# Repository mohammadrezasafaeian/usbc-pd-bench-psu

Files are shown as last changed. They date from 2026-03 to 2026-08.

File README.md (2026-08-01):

<div align="center">

# USB-C PD Bench Power Supply

### 0 – 36 V · 0 – 3 A · from a phone charger

4-switch synchronous buck-boost pre-regulator followed by a PNP-Darlington linear post-regulator —
laboratory-grade output from a USB-C source.





**[📄 Read the schematic →](sch.pdf)**

</div>

---

## Specification

| | |
|---|---|
| **Output** | 0 – 36 V, 0 – 3 A, continuously adjustable |
| **Max power** | limited by the source contract, not by the topology — see below |
| **Input** | USB-C — any PD contract, **or a legacy 5 V port**.  The buck-boost stage means the input voltage never limits the output voltage. |
| **Topology** | switching pre-regulator + linear post-regulator |
| **Ripple** | linear final stage — switching noise never reaches the output |
| **Protection** | polyfuse · 24 V TVS · hardware over-current under 1 µs · firmware OVP |
| **Control** | STM32G030C8T6, 5 kHz PI loop |
| **Interface** | 0.96″ OLED · rotary encoder · 3 keys · 10 indicator LEDs |

---

## Architecture

```mermaid
flowchart LR
    USB["USB-C input<br/>5 to 20 V"] --> PD["CH224K<br/>PD trigger"]
    PD --> BB["4-switch buck-boost<br/>250 kHz"]
    BB -->|"V_OUT + 2 V"| LIN["PNP Darlington<br/>linear post-reg"]
    LIN --> SNS["0R05 shunt<br/>INA181A2"]
    SNS --> OUT["OUTPUT<br/>0 to 36 V / 0 to 3 A"]
    MCU["STM32G030C8T6<br/>PWM, ADC, PI loop, PDO select"]
    MCU -.->|"CFG"| PD
    MCU -.->|"gate PWM"| BB
    MCU -.->|"V_REF"| LIN
    SNS -.->|"I sense"| MCU
    UI["OLED, encoder, keys"] -.-> MCU
    style USB fill:#e8f0fe,stroke:#1f6feb,stroke-width:2px
    style OUT fill:#fde8e8,stroke:#c62828,stroke-width:2px
    style BB fill:#e8f5e9,stroke:#2e7d32,stroke-width:2px
    style LIN fill:#e8f5e9,stroke:#2e7d32,stroke-width:2px
    style SNS fill:#e8f5e9,stroke:#2e7d32,stroke-width:2px
    style MCU fill:#fff4e5,stroke:#e07b00,stroke-width:2px
    style UI fill:#f3e5f5,stroke:#7b1fa2,stroke-width:2px
```

**Two stages, because neither alone is enough.** A switcher is efficient but noisy. A linear
regulator is quiet but burns the entire input-to-output difference as heat.

So the switcher does the bulk conversion and parks itself ~2 V above the target; the linear stage
drops only that last 2 V and absorbs all the ripple.

> Feeding the linear stage a fixed 20 V at 1 V / 3 A output would burn **57 W**.
> Tracking headroom keeps it near **6 W**.

Because the pre-regulator both bucks *and* boosts, the output voltage is independent of whatever
the charger negotiated. A 5 V source can drive a 36 V output; it just cannot drive it at 3 A.

---

## Adaptive PD negotiation

**The buck-boost stage decouples input from output.** Any negotiated voltage can produce any
output voltage — 20 V out from a 5 V contract works fine electrically (boost duty 0.77). The
contract does not limit the output *voltage*.

What it limits is **current**, because power has to balance:

| Contract | at 5 V out | at 12 V out | at 24 V out | at 36 V out |
|---|:---:|:---:|:---:|:---:|
| 5 V / 3 A — 15 W | 2.0 A | 0.9 A | 0.5 A | 0.3 A |
| 9 V / 3 A — 27 W | 3.0 A | 1.7 A | 0.9 A | 0.6 A |
| 12 V / 3 A — 36 W | 3.0 A | 2.3 A | 1.2 A | 0.8 A |
| 15 V / 3 A — 45 W | 3.0 A | 2.8 A | 1.5 A | 1.1 A |
| **20 V / 1.75 A — 35 W** | 3.0 A | 2.2 A | 1.2 A | 0.8 A |
| 20 V / 3 A — 60 W | 3.0 A | 3.0 A | 2.1 A | 1.4 A |

So a **35 W charger reaches 36 V out at ~0.8 A**, and 20 V at ~1.2 A. The contract never blocks a
voltage — it only caps the current. 3 A is the hardware ceiling set by the shunt and the pass
device.

### So why negotiate at all?

Two reasons, and neither is about reaching the voltage:

```mermaid
flowchart LR
    S(["V_OUT setpoint"]) --> WHY["pick the contract that<br/>keeps duty in range<br/>and has the power"]
    WHY --> A["0 to 4 V<br/>request 9 V"]
    WHY --> B["4 to 9 V<br/>request 12 V"]
    WHY --> C["9 to 13 V<br/>request 15 V"]
    WHY --> D["13 to 36 V<br/>request 20 V"]
    A --> A2["avoids tiny duty<br/>at low output"]
    B --> B2["duty 0.45 to 0.9"]
    C --> C2["headroom for current"]
    D --> D2["least step-up,<br/>best efficiency"]
    style S fill:#e8f0fe,stroke:#1f6feb,stroke-width:2px
    style WHY fill:#fff4e5,stroke:#e07b00,stroke-width:2px
    style A fill:#e8f5e9,stroke:#2e7d32
    style B fill:#e8f5e9,stroke:#2e7d32
    style C fill:#e8f5e9,stroke:#2e7d32
    style D fill:#e8f5e9,stroke:#2e7d32
```

**Duty-cycle range.** With 20 V in and 3 V out, the gate driver's 520 ns dead-time leaves only
~80 ns of real conduction and the loop pulse-skips. Requesting a lower voltage keeps the duty
cycle controllable.

**Efficiency.** Converting 20 V down to 5 V wastes more than converting 9 V down to 5 V. Picking
the nearest useful contract minimises the conversion ratio.

The firmware reads the source's advertised PDO list and takes the best available — it does not
assume 60 W is on offer. Boundaries carry 1.5 V of hysteresis, and the output is disabled during
renegotiation.

---

## Design highlights

<table>
<tr><td width="50%" valign="top">

### 🔌 Works on any USB-C port

Full PD gets the whole 0–20 V range. A **legacy 5 V port** still boots and runs, clamped to what
it can deliver.

Two details make that work:

- the logic LDO is fed from the **+12 V rail**, not VBUS — a legacy port sits at ~4.75 V, below
  the regulator's dropout
- **CFG1 is pulled high**, so a bare board requests 5 V before firmware even runs

</td><td width="50%" valign="top">

### 🛡 Protection that doesn't need firmware

A comparator pulls both gate drivers down in **under 1 µs**, independent of the MCU.

The fault LED lights **even if the processor has crashed** — which is the entire point of a
hardware trip.

Firmware then latches the fault and holds the output off until it's cleared.

</td></tr>
<tr><td valign="top">

### 🛑 Output kill is never in a menu

A **dedicated OUTPUT key** on its own interrupt.

If the board under test starts smoking, one press stops it — no scrolling, no mode, no waiting
for the UI task to notice.

</td><td valign="top">

### 🔍 24 test points

Kelvin taps at the current shunt, paired grounds so every scope probe has a short return, and
1.0 mm pads on the switch nodes to keep copper on the high-dv/dt net minimal.

</td></tr>
</table>

---

## Control loop

```mermaid
flowchart LR
    SET(["V_SET from UI"]) --> DAC["PWM-DAC<br/>2-pole RC"]
    DAC --> EA["Error amp<br/>LM358"]
    FB["Output divider"] --> EA
    EA --> PASS["PNP Darlington<br/>base drive"]
    PASS --> VOUT(["V_OUT"])
    VOUT --> FB
    VOUT -.->|"ADC"| PI["PI loop<br/>5 kHz"]
    PI -.->|"V_PRE tracks V_OUT"| PRE["Buck-boost duty"]
    ISNS["Shunt + INA181A2"] -.-> PI
    ISNS -.->|"over 3.2 A"| TRIP["Comparator<br/>under 1 us"]
    TRIP -.->|"SHDN_N"| PRE
    style SET fill:#e8f0fe,stroke:#1f6feb
    style VOUT fill:#fde8e8,stroke:#c62828,stroke-width:2px
    style TRIP fill:#fde8e8,stroke:#c62828,stroke-width:2px
    style PI fill:#fff4e5,stroke:#e07b00
```

Headroom is **adaptive**, not a flat 2 V:

```
V_head = clamp(1.6 V + 0.35 Ω × I_out,  2.0 V,  3.0 V)
```

Slew-limited so the pre-regulator leads on rising steps and lags on falling ones — V_PRE must
never dip below V_OUT + V_CE(sat).

---

## User interface

| Control | Function |
|---|---|
| **Rotary encoder** | adjust the selected field |
| **Encoder push** | coarse / fine step (×1 · ×10 · ×100) |
| **OUTPUT** | dedicated on/off — own interrupt, always responsive |
| **SELECT** | cycle V-set → I-limit → digit |
| **BACK** | back; long-press clears a latched fault |

**10 indicator LEDs** — three rail-health, output live, constant-current mode, firmware heartbeat,
PD contract status, fault, and UART activity.

Seven are driven directly by hardware, which is deliberate:

- **PD_PG** is driven by the PD controller itself — it shows at a glance whether you got a real
  contract or fell back to legacy 5 V
- **FAULT** is driven by the over-current comparator, so it lights *even when the MCU is dead*.
  A firmware-driven fault lamp cannot do that.

The remaining three — **OUT**, **CC** and **HB** — are on GPIO, and the firmware uses them as a
diagnostic code so a fault can be identified without a scope or a serial cable.

### Planned blink codes

> Firmware is not yet written. This is the diagnostic scheme the hardware supports.

`HB` carries the rhythm; `OUT` and `CC` encode the fault as two bits.

| HB | OUT | CC | Meaning |
|:---|:---:|:---:|:---|
| steady 1 Hz | — | — | running normally |
| 2 blinks | off | off | over-current trip |
| 2 blinks | **on** | off | over-voltage |
| 2 blinks | off | **on** | over-temperature |
| 2 blinks | **on** | **on** | pre-regulator lost tracking |
| 3 blinks | off | off | PD negotiation failed |
| 3 blinks | **on** | off | legacy 5 V port — output range clamped |
| 3 blinks | off | **on** | ADC or reference out of range |
| solid on | **on** | **on** | firmware fault — watchdog reset pending |

Three GPIO-driven LEDs give **8 distinguishable fault states**, and the two hardware-driven lamps
(PD_PG, FAULT) stay valid even if the processor has stopped — so a dead MCU is itself
diagnosable.

---

## Engineering decisions worth asking about

> These are the judgement calls. Reasoning is in [`AUTHORSHIP.md`](AUTHORSHIP.md) and in notes on
> the sheets themselves.

- **The ground plane is not split** between the switching and linear sections. The stages are in
  *series*, so there is one return current — a slot would force it to detour and enlarge the loop.
  Separation is done by placement, with the analog reference starred at the output cap negative.
- **The current shunt is high-side**, so the output negative stays at true ground and the sense
  network carries only microamps.
- **The pass device is a PNP Darlington**, not an NPN follower — an NPN would need V_OUT + 1 V of
  drive, impossible at the top of the range.
- **Linear headroom is adaptive** and slew-limited, not a fixed offset.

---

## Firmware

Bare-metal C, no HAL. **3.0 KB flash, 40 bytes RAM.**

```bash
cd firmware && make
```

The analogue loop does the fast regulation; firmware supervises:

| Layer | Does | Speed |
|---|---|---|
| LM358 + PNP Darlington | holds V_OUT at the reference | analogue |
| Comparator → SHDN_N | kills the drivers on over-current | < 1 µs, no MCU |
| Firmware PI loop | keeps V_PRE ≈ V_OUT + headroom | 5 kHz |
| Supervisor | limits, PDO choice, UI, diagnostics | 100 Hz |

### Battery emulation

A cell sags under load, and that is the entire model:

```c
V_out = V_oc − I_load × R_internal
```

Both adjustable from the panel — 3.7 V / 100 mΩ for a Li-ion cell, 12.6 V /
20 mΩ for a small lead-acid pack. The current sense and voltage reference are
already in the loop, so this needs no extra hardware.

**Source-side only.** A real battery accepts charge; sinking current needs a
two-quadrant output stage, which the PNP pass device cannot do. That is the
next hardware revision.

See [`firmware/README.md`](firmware/README.md) for the pin map and the
diagnostic blink codes.

---

## Verification

| Check | Result |
|---|---|
| KiCad ERC errors | **0** |
| Orphan / unconnected parts | **0** |
| Dangling or single-pin nets | **0** |
| Shorted two-terminal parts | **0** |
| Auto-named nets | **0** — all **85** nets named for layout |
| Items off-page or clashing with the title block | **0** |
| Analogue nets on real ADC channels | **6 / 6** |
| Firmware pin map vs schematic netlist | **27 / 27 match** |
| Firmware build | **clean, 0 warnings** |

Several faults were caught during checking that had passed visual inspection — a pass transistor
whose collector and emitter had landed on the same net, six UI inputs chained together through
their debounce grounds, and reversed LED polarity. Details in [`AUTHORSHIP.md`](AUTHORSHIP.md).

---

## Revision history

| Rev | Status | What changed |
|---|---|---|

| **early** | superseded | single-sheet layout — included as page 4 of the PDF |
| **v1.1** | superseded | snubbers · +12 V gate rail on-sheet · hardware OCP · IRS2104 drivers · INA181A2 sense · STM32G030C8T6 · full UI. Output 0–20 V. |
| **v1.2** | **current** | output range raised to **0–36 V** (63 V bulk caps, rescaled dividers); all analogue nets moved onto real ADC channels; firmware added |

The earlier single-sheet revision had no snubbers on the switch nodes and left the +12 V gate
rail as an off-sheet module. Both are resolved here.

---

## Repository

| File | |
|---|---|
| **[`sch.pdf`](sch.pdf)** | **4-page schematic — start here** |
| **[`docs/design-evolution.pdf`](docs/design-evolution.pdf)** | **how the design got here — every revision, v0.3 to v1.3** |
| `usbc_pd_psu.kicad_sch` | KiCad 9 project (root sheet) |
| `power.kicad_sch` | sheet 1 — input, PD trigger, 12 V rail, buck-boost, drivers, OCP |
| `control.kicad_sch` | sheet 2 — post-regulator, current sense, MCU, UI |
| `bom.csv` · `netlist.net` · `erc.rpt` | outputs |
| `firmware/` | bare-metal C: control loop, battery emulation, diagnostics (`hw` / `control` / `pd` / `ui`) |
| [`AUTHORSHIP.md`](AUTHORSHIP.md) | design reasoning and provenance |

Drawn in **KiCad 9** using stock symbol and footprint libraries only — no custom parts, so the
project opens cleanly on any KiCad 9 installation.

---

## Status and honest caveats

> **Design complete, not yet built.** No hardware has been assembled or tested.

Known open items, carried deliberately:

- Dead-time is **13 % of the switching period** at 250 kHz. Dropping to 150 kHz with a 47 µH
  inductor would cut it to 7.8 %, at the cost of a physically larger inductor.
- V_PRE reaches 39 V at full output. The 60 V bridge FETs keep 54 % margin; output and V_PRE
  bulk caps are 63 V parts. Going beyond 36 V would need 100 V FETs.
- Input capacitance exceeds the USB hot-plug limit. PD sources tolerate it in practice; strict
  compliance needs a soft-start FET.

---

<div align="center">

**Mohammadreza Safaeian**

[m.re.safaeian@gmail.com](mailto:m.re.safaeian@gmail.com) · [github.com/mohammadrezasafaeian](https://github.com/mohammadrezasafaeian)

© 2026 Mohammadreza Safaeian. All rights reserved — see [LICENSE](LICENSE).

</div>

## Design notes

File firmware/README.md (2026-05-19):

# Firmware

Bare-metal C for the STM32G030C8T6. No HAL, no RTOS.

```
firmware/
  main.c          init and the 5 kHz / 100 Hz loop
  hw.c            GPIO, ADC, PWM  — the only file that touches registers
  control.c       PI loop, current limit, battery emulation
  pd.c            PDO selection and renegotiation
  ui.c            encoder, buttons, LED codes
  psu.h           shared state and cross-module declarations
  board.h         pin map, divider ratios, limits
  stm32g030.h     register map
  startup.c       vector table, .data / .bss setup
  stm32g030.ld    64 KB flash, 8 KB RAM
  Makefile
```

`board.h` is the only file that changes if the wiring changes.

## Build

```bash
cd firmware
make            # -> main.elf, main.bin
make flash      # OpenOCD over SWD
```

Needs `gcc-arm-none-eabi`. **3.0 KB flash (4.7 %)**, **40 bytes RAM (0.5 %)**.

---

## How the regulation is split

| Layer | Does | Speed |
|---|---|---|
| LM358 + PNP Darlington | holds V_OUT at the reference | analogue |
| Comparator + SHDN_N | kills the drivers on over-current | < 1 µs, no MCU |
| Firmware PI loop | keeps V_PRE ≈ V_OUT + headroom | 5 kHz |
| Firmware supervisor | limits, PDO choice, UI, diagnostics | 100 Hz |

Firmware never regulates the output directly. It sets the reference through a
PWM DAC and keeps the pre-regulator a sensible distance above the output:

```c
V_head = clamp(2.0 V + 0.35 Ω × I_out, 2.0 V, 3.0 V)
```

A flat 2 V is thin at 3 A once Darlington saturation, the shunt drop and the
switcher's droop are added up.

`SHDN_N` is open drain and wired-AND with the comparator, so firmware can only
*assert* shutdown — never override the hardware trip.

---

## Modes

**Supply** — constant voltage with a current limit. At the limit the firmware
walks the reference down and lights CC; the analogue loop does the limiting.

**Battery** — a cell sags under load, and that is the whole model:

```c
V_out = V_oc − I_load × R_internal
```

Both adjustable from the panel — 3.7 V / 100 mΩ for a Li-ion cell, 12.6 V /
20 mΩ for a small lead-acid pack.

Source side only: a real battery accepts charge, and the PNP cannot sink. That
needs a two-quadrant output stage — the next hardware revision.

---

## PDO selection

The buck-boost decouples input from output, so **any contract reaches any
output voltage**. What a contract limits is *current*.

| Setpoint | Requests | Why |
|---|---|---|
| 0 – 4 V | 9 V | keeps duty off the dead-time floor |
| 4 – 9 V | 12 V | |
| 9 – 13 V | 15 V | |
| 13 – 36 V | 20 V | least step-up ratio |

On a legacy 5 V-only port the range clamps to 4 V and `FAULT_LEGACY_CLAMP`
lights — the supply still works, with a smaller envelope. The output is
dropped across a renegotiation, because VBUS collapses briefly.

---

## Diagnostic codes

Three LEDs are on GPIO; the other seven are wired to hardware signals, so the
fault lamp still works when the MCU is dead.

| HB | OUT | CC | Meaning |
|---|---|---|---|
| 1 Hz heartbeat | output live | in CC | normal |
| 2 blinks | · | · | over-current |
| 2 blinks | on | · | over-voltage |
| 2 blinks | · | on | over-temperature |
| 2 blinks | on | on | tracking — pre-reg lost the output |
| 3 blinks | · | · | PD negotiation failed |
| 3 blinks | on | · | legacy 5 V port, range clamped |
| solid | on | on | firmware fault |

Press **OUTPUT** to clear a fault and toggle the output, or hold **BACK** for
about a second to clear it without touching the output.

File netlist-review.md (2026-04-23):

# Netlist review

Checks run against the exported netlist rather than the drawing, because
most of these are invisible on a sheet that looks correct.

| Check | Result |
|---|---|
| every part has a footprint | pass |
| no two-terminal part shorted end to end | pass |
| no net with a single node | pass |
| no two labels differing only by case or a character | pass |
| every symbol inside a sheet frame | pass |
| every MCU pin either assigned or explicitly no-connect | pass |
| analogue nets land on pins that have an ADC channel | **fail** |
| feedback divider reaches the error amplifier | **fail** |

## Analogue nets on pins with no ADC

`ADC_VBUS`, `ADC_VPRE`, `ADC_VOUT` and `ISNS_OUT` sit on PD2, PD3, PC6 and
PC7.  None of those has an ADC channel on this part, so not one of the four
measurements can be taken.  They need to move to PA0, PA1, PA4 and PA5.

## Feedback divider does not reach the error amplifier

`VOUT_FB` reaches only an MCU analogue input.  The error amplifier's
inverting input is on a separate net that sees only its compensation
capacitor, so the loop has no DC path around it.  Both need to be one node.

The first is fixed in the next revision.  The second is deeper than a pin
move and is carried forward.

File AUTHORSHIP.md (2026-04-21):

# Authorship and provenance

**Author:** Mohammadreza Safaeian
**Contact:** m.re.safaeian@gmail.com · mohammad.rsafaeian@gmail.com
**Repository:** https://github.com/mohammadrezasafaeian
**Copyright:** © 2026 Mohammadreza Safaeian. All rights reserved.

This is an original design. It is not derived from a reference design, an
application-note schematic, or any downloaded project.

---

## What makes that checkable

Anyone can type a name into a title block. These are the things that are
actually hard to fake, in descending order of usefulness:

### 1. The design evolved through revisions, and the earlier one is included

`docs/earlier-revision.png` is my previous KiCad revision (the earlier revision:
CH32V003 MCU, IR2104 drivers, discrete LM358 current sense). It is bound into
`sch.pdf` as page 4.

Rev C is the redraw that fixes the problems in it:

| the earlier revision (previous) | Rev C (this design) |
|---|---|
| no snubbers on the switch nodes | RC snubbers (4R7 + 2n2) on both |
| +12 V gate rail left as an off-sheet module — **unbuildable** | MT3608 boost on-sheet |
| IR2104 drivers (V_IH out of spec at 3.3 V) | IRS2104 (V_IH 2.5 V) |
| discrete LM358 current sense | INA181A2 + 0R05 shunt |
| CH32V003 — out of I/O once the UI was added | STM32G030C8T6, ~18 pins spare |
| no hardware over-current path | LM2903 trip, < 1 µs, firmware-independent |
| logic LDO fed from VBUS — fails on a legacy 5 V port | fed from +12 V |

Downloaded schematics do not come with the author's own superseded revision
and a defensible list of what was wrong with it.

### 2. The design was verified, not just drawn

Beyond KiCad's own ERC, the design was checked for connectivity and layout
faults:

| Check | Looks for |
|---|---|
| connectivity | dangling wire endpoints, wires crossing pins, shorted two-pin parts |
| netlist | orphan parts, unnamed nets, single-pin nets |
| page fit | items off-page, title-block clashes, overlapping notes |
| peripherals | every analogue net on a real ADC channel |

### 3. Faults found during checking, and how they were fixed

These are recorded because they show the work, not just the result. Each one
passed a visual inspection and was caught by a programmatic check:

- **Instance-path mismatch** — sheet symbols on the root page carried different
  UUIDs from the ones the child sheets quoted, so KiCad silently dropped five
  parts (including L2, the main inductor) from the netlist.
- **Q5 collector shorted to its emitter** — the pass transistor was bypassed
  entirely; `VPRE` and `VOUT` resolved to the same net.
- **Every UI input shorted to GND** — the debounce RC stack is ~19 mm tall but
  rows were pitched 12–16 mm, so each ground stub landed on the next row's
  signal node, chaining six inputs plus GND into one 84-node net.
- **All three keys shorted to GND** — the compact RC leg put the cap *on* the
  row, so the horizontal label wire ran straight through the cap and its
  ground symbol.
- **Encoder B shorted to S1** — a vertical drop crossed another contact's
  horizontal run.
- **LED polarity reversed** — MCU pins were driving cathodes.
- **Duplicate stacked wires** — two identical segments make KiCad drop the
  connection entirely.

### 4. Design decisions I can defend

The reasoning behind these is in `README.md` and in notes on the sheets
themselves. They are the questions worth asking me about:

- Why the current shunt is **high-side** rather than in the output return.
- Why the ground plane is **not split** between the switching and linear
  stages, despite that being a common instinct.
- Why the PD contract is **chosen per setpoint** rather than pinned at 20 V —
  and why 9 V, not 5 V, is the floor.
- Why the pass device is a **PNP Darlington** and not an NPN follower.
- Why the linear headroom is **adaptive** rather than a flat 2 V.
- Why 250 kHz costs 13 % of the period to dead-time, and what 150 kHz buys.

### 5. Commit history

`git log` shows the design being built and corrected over time, with each fix
in its own commit.

---

## Verification status

| Check | Result |
|---|---|
| KiCad ERC errors | 0 |
| KiCad ERC warnings | 5 `lib_symbol_mismatch` (cosmetic — see README) |
| Orphan parts | 0 |
| Dangling / single-pin nets | 0 (18 explicit no-connects excluded) |
| Auto-named `Net-(...)` nets | 0 — all 85 real nets carry names |
| Shorted two-terminal parts | 0 |
| Off-page items / title-block clashes | 0 |

---

## Licence

© 2026 Mohammadreza Safaeian. All rights reserved. See `LICENSE`.

The design is published for portfolio and evaluation purposes. No licence to
manufacture, redistribute, or create derivative works is granted. If you would
like to use any part of it, please get in touch.

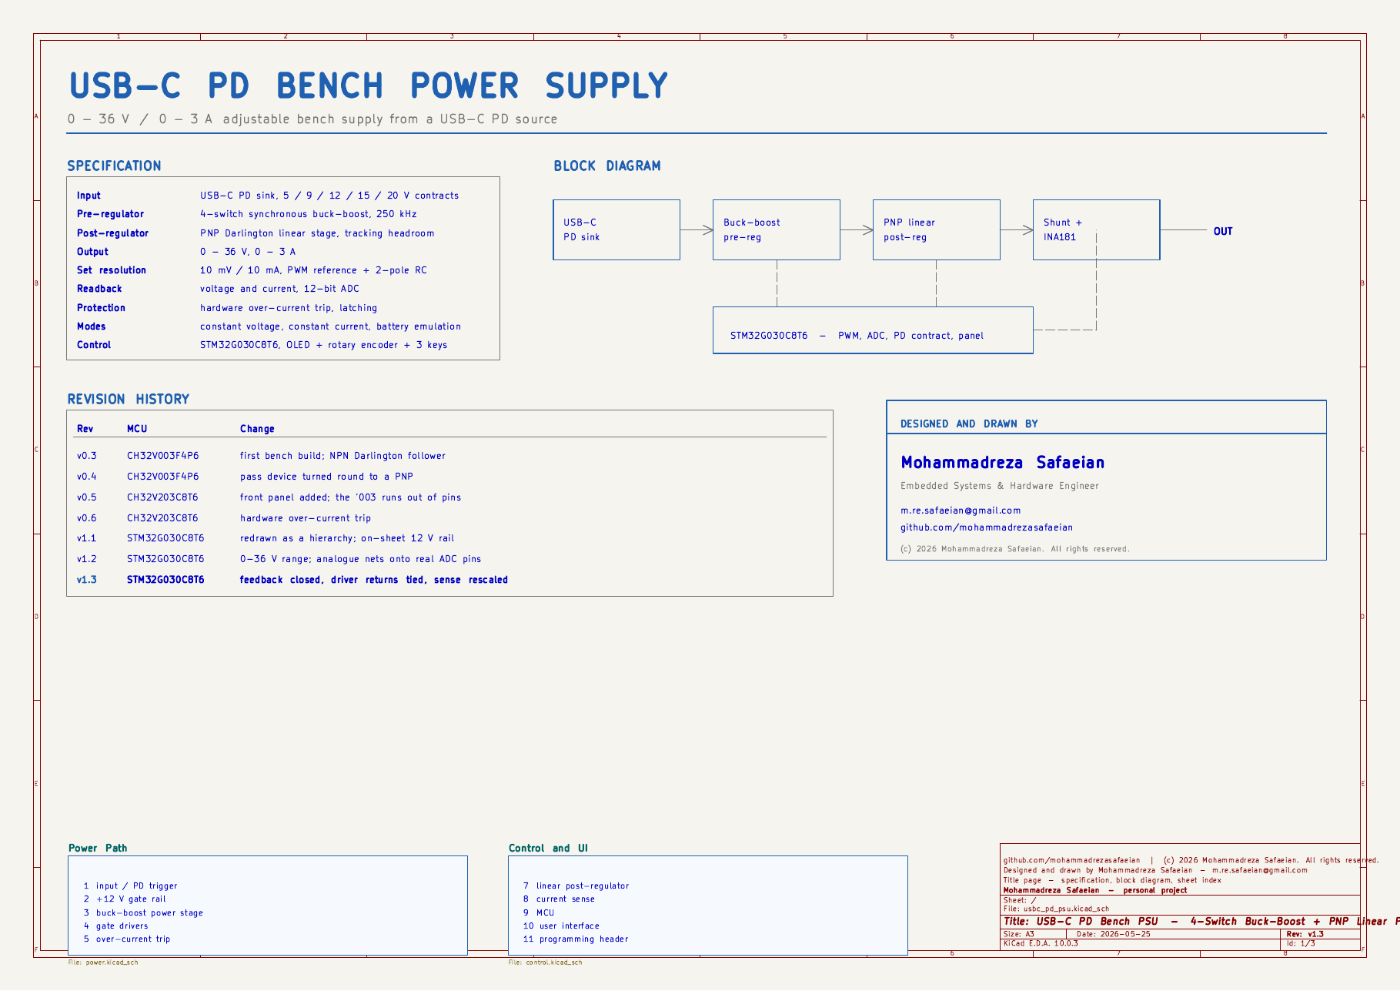
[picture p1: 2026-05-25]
preview-1-title.png

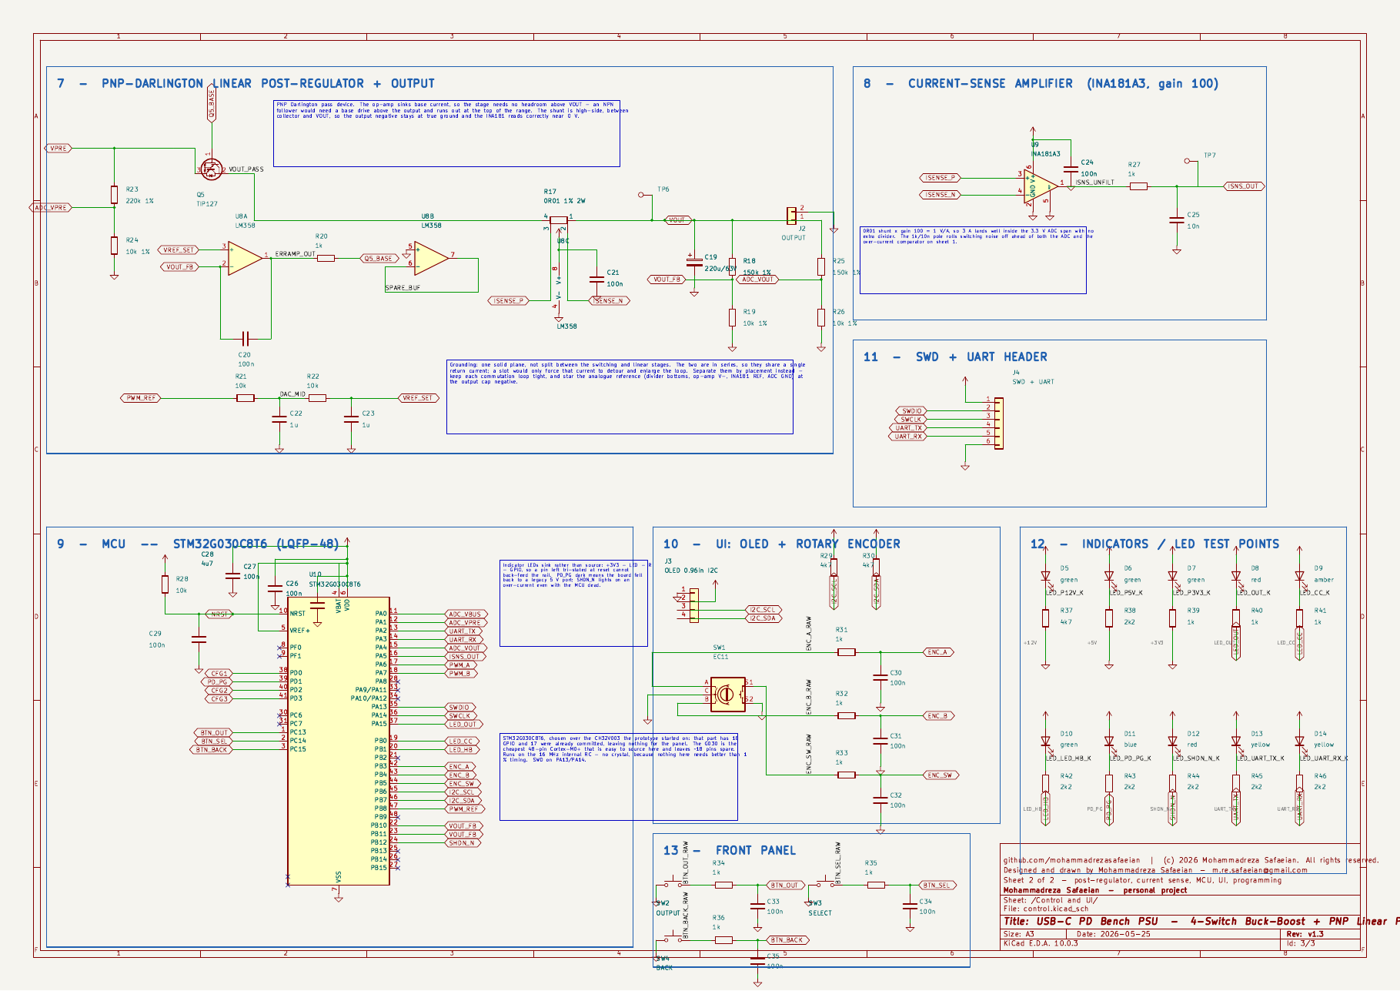
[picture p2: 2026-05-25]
preview-3-control.png

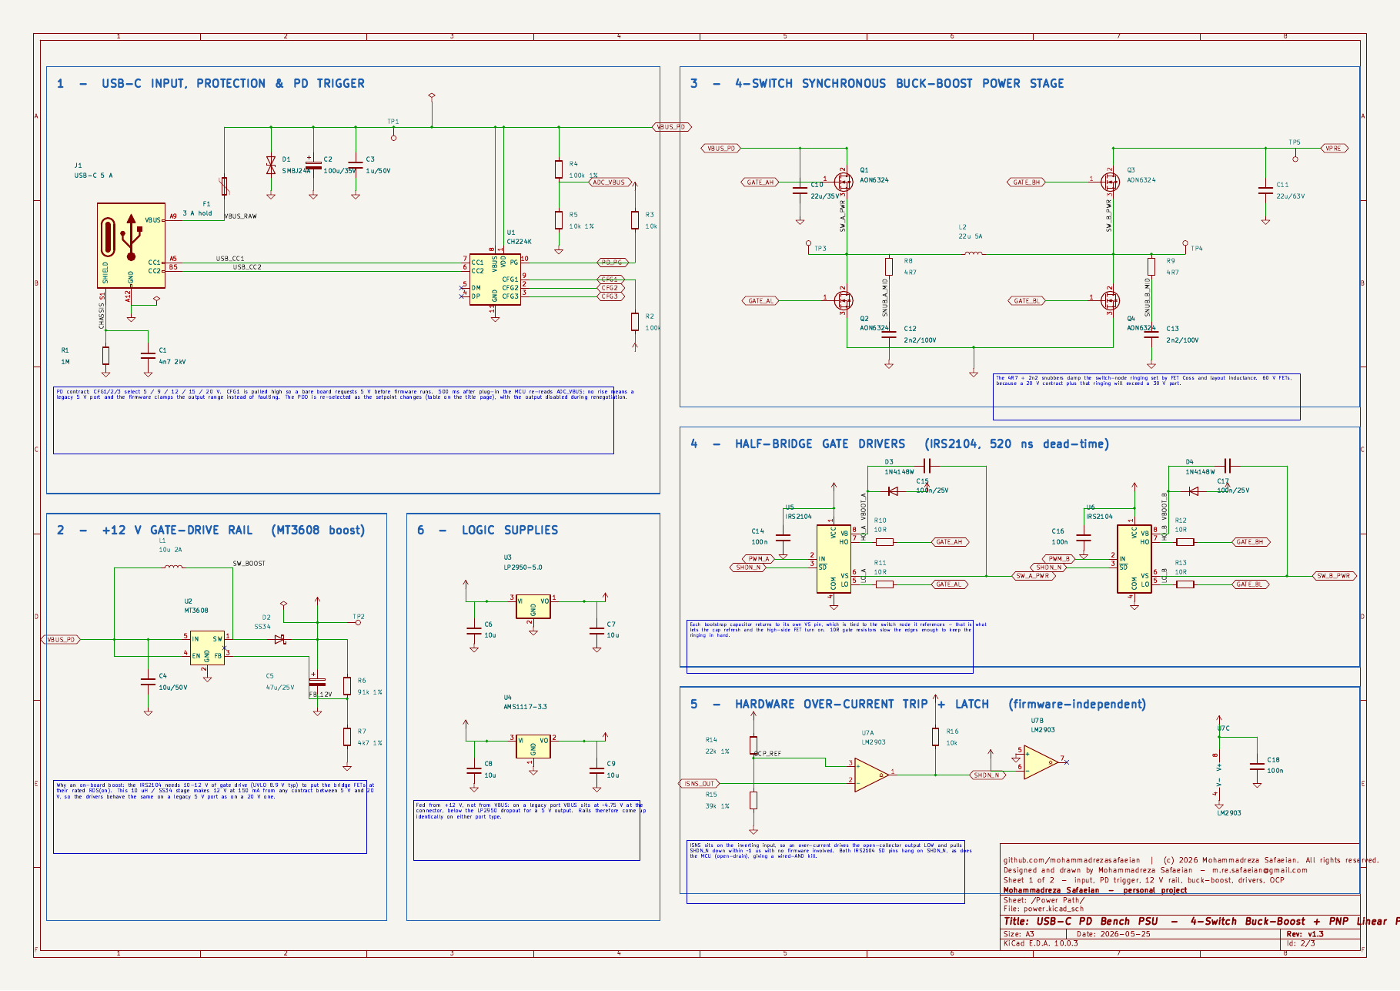
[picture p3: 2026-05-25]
preview-2-power.png

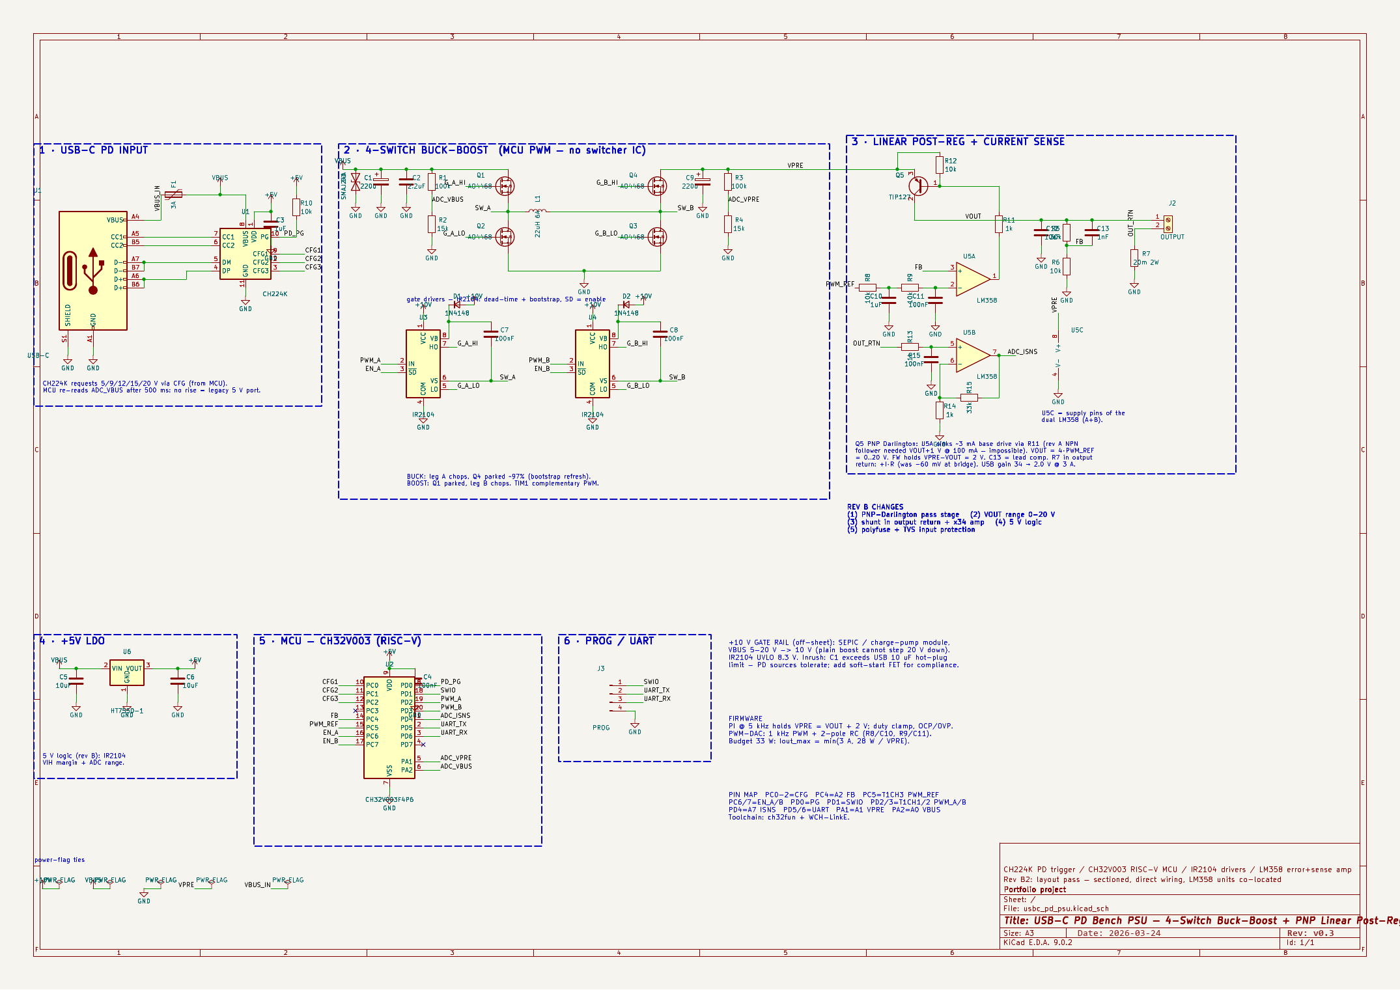
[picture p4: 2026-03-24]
docs/earlier-revision.png

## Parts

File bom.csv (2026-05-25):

Reference | Value | Footprint
C1 | 4n7 2kV | Capacitor_SMD:C_0805_2012Metric
C2 | 100u/35V | Capacitor_SMD:CP_Elec_6.3x7.7
C3 | 1u/50V | Capacitor_SMD:C_0805_2012Metric
C4 | 10u/50V | Capacitor_SMD:C_0805_2012Metric
C5 | 47u/25V | Capacitor_SMD:CP_Elec_6.3x7.7
C6 | 10u | Capacitor_SMD:C_0805_2012Metric
C7 | 10u | Capacitor_SMD:C_0805_2012Metric
C8 | 10u | Capacitor_SMD:C_0805_2012Metric
C9 | 10u | Capacitor_SMD:C_0805_2012Metric
C10 | 22u/35V | Capacitor_SMD:C_0805_2012Metric
C11 | 22u/63V | Capacitor_SMD:C_0805_2012Metric
C12 | 2n2/100V | Capacitor_SMD:C_0805_2012Metric
C13 | 2n2/100V | Capacitor_SMD:C_0805_2012Metric
C14 | 100n | Capacitor_SMD:C_0805_2012Metric
C15 | 100n/25V | Capacitor_SMD:C_0805_2012Metric
C16 | 100n | Capacitor_SMD:C_0805_2012Metric
C17 | 100n/25V | Capacitor_SMD:C_0805_2012Metric
C18 | 100n | Capacitor_SMD:C_0805_2012Metric
C19 | 220u/63V | Capacitor_SMD:CP_Elec_6.3x7.7
C20 | 100n | Capacitor_SMD:C_0805_2012Metric
C21 | 100n | Capacitor_SMD:C_0805_2012Metric
C22 | 1u | Capacitor_SMD:C_0805_2012Metric
C23 | 1u | Capacitor_SMD:C_0805_2012Metric
C24 | 100n | Capacitor_SMD:C_0805_2012Metric
C25 | 10n | Capacitor_SMD:C_0805_2012Metric
C26 | 100n | Capacitor_SMD:C_0805_2012Metric
C27 | 100n | Capacitor_SMD:C_0805_2012Metric
C28 | 4u7 | Capacitor_SMD:C_0805_2012Metric
C29 | 100n | Capacitor_SMD:C_0805_2012Metric
C30 | 100n | Capacitor_SMD:C_0805_2012Metric
C31 | 100n | Capacitor_SMD:C_0805_2012Metric
C32 | 100n | Capacitor_SMD:C_0805_2012Metric
C33 | 100n | Capacitor_SMD:C_0805_2012Metric
C34 | 100n | Capacitor_SMD:C_0805_2012Metric
C35 | 100n | Capacitor_SMD:C_0805_2012Metric
D1 | SMBJ24A | Diode_SMD:D_SMA
D2 | SS34 | Diode_SMD:D_SMA
D3 | 1N4148W | Diode_SMD:D_SOD-123
D4 | 1N4148W | Diode_SMD:D_SOD-123
D5 | green | LED_SMD:LED_0805_2012Metric
D6 | green | LED_SMD:LED_0805_2012Metric
D7 | green | LED_SMD:LED_0805_2012Metric
D8 | red | LED_SMD:LED_0805_2012Metric
D9 | amber | LED_SMD:LED_0805_2012Metric
D10 | green | LED_SMD:LED_0805_2012Metric
D11 | blue | LED_SMD:LED_0805_2012Metric
D12 | red | LED_SMD:LED_0805_2012Metric
D13 | yellow | LED_SMD:LED_0805_2012Metric
D14 | yellow | LED_SMD:LED_0805_2012Metric
F1 | 3 A hold | Fuse:Fuse_1206_3216Metric
J1 | USB-C 5 A | Connector_USB:USB_C_Receptacle_XKB_U262-16XN-4BVC11
J2 | OUTPUT | Connector_PinSocket_2.54mm:PinSocket_1x02_P2.54mm_Vertical
J3 | OLED 0.96in I2C | Connector_PinHeader_2.54mm:PinHeader_1x04_P2.54mm_Vertical
J4 | SWD + UART | Connector_PinHeader_2.54mm:PinHeader_1x06_P2.54mm_Vertical
L1 | 10u 2A | Inductor_SMD:L_12x12mm_H8mm
L2 | 22u 5A | Inductor_SMD:L_12x12mm_H8mm
Q1 | AON6324 | Package_TO_SOT_SMD:TO-263-2
Q2 | AON6324 | Package_TO_SOT_SMD:TO-263-2
Q3 | AON6324 | Package_TO_SOT_SMD:TO-263-2
Q4 | AON6324 | Package_TO_SOT_SMD:TO-263-2
Q5 | TIP127 | Package_TO_SOT_THT:TO-220-3_Vertical
R1 | 1M | Resistor_SMD:R_0805_2012Metric
R2 | 100k | Resistor_SMD:R_0805_2012Metric
R3 | 10k | Resistor_SMD:R_0805_2012Metric
R4 | 100k 1% | Resistor_SMD:R_0805_2012Metric
R5 | 10k 1% | Resistor_SMD:R_0805_2012Metric
R6 | 91k 1% | Resistor_SMD:R_0805_2012Metric
R7 | 4k7 1% | Resistor_SMD:R_0805_2012Metric
R8 | 4R7 | Resistor_SMD:R_0805_2012Metric
R9 | 4R7 | Resistor_SMD:R_0805_2012Metric
R10 | 10R | Resistor_SMD:R_0805_2012Metric
R11 | 10R | Resistor_SMD:R_0805_2012Metric
R12 | 10R | Resistor_SMD:R_0805_2012Metric
R13 | 10R | Resistor_SMD:R_0805_2012Metric
R14 | 22k 1% | Resistor_SMD:R_0805_2012Metric
R15 | 39k 1% | Resistor_SMD:R_0805_2012Metric
R16 | 10k | Resistor_SMD:R_0805_2012Metric
R17 | 0R01 1% 2W | Resistor_SMD:R_2512_6332Metric
R18 | 150k 1% | Resistor_SMD:R_0805_2012Metric
R19 | 10k 1% | Resistor_SMD:R_0805_2012Metric
R20 | 1k | Resistor_SMD:R_0805_2012Metric
R21 | 10k | Resistor_SMD:R_0805_2012Metric
R22 | 10k | Resistor_SMD:R_0805_2012Metric
R23 | 220k 1% | Resistor_SMD:R_0805_2012Metric
R24 | 10k 1% | Resistor_SMD:R_0805_2012Metric
R25 | 150k 1% | Resistor_SMD:R_0805_2012Metric
R26 | 10k 1% | Resistor_SMD:R_0805_2012Metric
R27 | 1k | Resistor_SMD:R_0805_2012Metric
R28 | 10k | Resistor_SMD:R_0805_2012Metric
R29 | 4k7 | Resistor_SMD:R_0805_2012Metric
R30 | 4k7 | Resistor_SMD:R_0805_2012Metric
R31 | 1k | Resistor_SMD:R_0805_2012Metric
R32 | 1k | Resistor_SMD:R_0805_2012Metric
R33 | 1k | Resistor_SMD:R_0805_2012Metric
R34 | 1k | Resistor_SMD:R_0805_2012Metric
R35 | 1k | Resistor_SMD:R_0805_2012Metric
R36 | 1k | Resistor_SMD:R_0805_2012Metric
R37 | 4k7 | Resistor_SMD:R_0805_2012Metric
R38 | 2k2 | Resistor_SMD:R_0805_2012Metric
R39 | 1k | Resistor_SMD:R_0805_2012Metric
R40 | 1k | Resistor_SMD:R_0805_2012Metric
R41 | 1k | Resistor_SMD:R_0805_2012Metric
R42 | 2k2 | Resistor_SMD:R_0805_2012Metric
R43 | 2k2 | Resistor_SMD:R_0805_2012Metric
R44 | 2k2 | Resistor_SMD:R_0805_2012Metric
R45 | 2k2 | Resistor_SMD:R_0805_2012Metric
R46 | 2k2 | Resistor_SMD:R_0805_2012Metric
SW1 | EC11 | Rotary_Encoder:RotaryEncoder_Alps_EC11E-Switch_Vertical_H20mm
SW2 | OUTPUT | Button_Switch_SMD:SW_SPST_B3S-1000
SW3 | SELECT | Button_Switch_SMD:SW_SPST_B3S-1000
SW4 | BACK | Button_Switch_SMD:SW_SPST_B3S-1000
TP1 | TP_VBUS | TestPoint:TestPoint_Pad_D1.5mm
TP2 | TP_12V | TestPoint:TestPoint_Pad_D1.5mm
TP3 | TP_SWA | TestPoint:TestPoint_Pad_D1.0mm
TP4 | TP_SWB | TestPoint:TestPoint_Pad_D1.0mm
TP5 | TP_VPRE | TestPoint:TestPoint_Pad_D1.5mm
TP6 | TP_VOUT | TestPoint:TestPoint_Pad_D1.5mm
TP7 | TP_ISNS | TestPoint:TestPoint_Pad_D1.5mm
U1 | CH224K | Package_SO:SSOP-10-1EP_3.9x4.9mm_P1mm_EP2.1x3.3mm
U2 | MT3608 | Package_TO_SOT_SMD:SOT-23-5
U3 | LP2950-5.0 | Package_TO_SOT_SMD:SOT-223-3_TabPin2
U4 | AMS1117-3.3 | Package_TO_SOT_SMD:SOT-223-3_TabPin2
U5 | IRS2104 | Package_SO:SOIC-8_3.9x4.9mm_P1.27mm
U6 | IRS2104 | Package_SO:SOIC-8_3.9x4.9mm_P1.27mm
U7 | LM2903 | Package_SO:SOIC-8_3.9x4.9mm_P1.27mm
U8 | LM358 | Package_SO:SOIC-8_3.9x4.9mm_P1.27mm
U9 | INA181A3 | Package_TO_SOT_SMD:SOT-23-5
U10 | STM32G030C8T6 | Package_QFP:LQFP-48_7x7mm_P0.5mm

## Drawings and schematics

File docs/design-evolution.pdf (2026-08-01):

# USB-C PD Bench Power Supply

# schematic evolution, v0.3 through v1.3

# How the design moved

Rev | Dates | MCU | Sheet | What changed, and why
v0.3 | 24 Mar | CH32V003F4P6 | single A3 | First arrangement that worked on the bench. Four-switch buck–boost
| | | | driven straight from MCU PWM, and a TIP120 NPN Darlington
| | | | emitter follower as the pass device — the obvious way to build the
| | | | stage. Set over UART: there is no panel, because every usable pin is
| | | | already committed.
v0.4 | 25 Mar | CH32V003F4P6 | single A3 | The pass device turns round. The NPN follower needs its base two
| | | | VBE above the output, and the op-amp driving it runs from the same
| | | | pre-regulator rail, so it saturates before the top of the range. A TIP127
| | | | PNP Darlington sinks base current instead and needs no headroom above
| | | | VOUT at all.
v0.5 | 26 Mar | CH32V203C8T6 | single A3 | User interface added. The ’003 has 18 usable GPIO and 16 were spent
| | | | on the power path, leaving two — not enough for an encoder, three keys,
| | | | three lamps and a display. Moving up the same RISC-V family to the
| | | | 48-pin part brings 37 GPIO and keeps the toolchain unchanged.
v0.6 | 27 Mar | CH32V203C8T6 | single A3 | Hardware over-current trip added after bench testing showed
| | | | firmware alone cannot react to a short in time. This is the last thing
| | | | that fits on one sheet.

## 10 days idle — prototype left on the bench

v1.1 | 5–15 Apr | STM32G030C8T6 | 3-sheet | Redrawn as a hierarchy, and the MCU changes vendor. The +12 V
| | | | gate rail becomes a real on-sheet boost instead of an off-sheet module,
| | | | so the board can actually be built; RC snubbers are added across both
| | | | switch nodes; the drivers gain proper bootstrap networks.
v1.2 | 25 Apr | STM32G030C8T6 | 3-sheet | 0–36 V range, and the analogue nets move onto pins that have
| | | | an ADC. v1.1 had put ADC VBUS, ADC VPRE, ADC VOUT and
| | | | ISNS OUT on PD2, PD3, PC6 and PC7 — none of which has an ADC
| | | | channel on this part, so not one of the four measurements could have been
| | | | taken.
v1.3 | 25 May | STM32G030C8T6 | 3-sheet | The three faults that would have stopped the board working.
| | | | See below.

# What v1.3 fixes

Fault | Effect if built | Fix
Feedback loop never closed | The output divider tap and the error amplifier’s invert-

## ing input were two separate nets. U8A had no DC feedback path at all: a bare integrator whose output ramps to a rail. The pass device would sit hard on or hard off

— the supply would not regulate, it would latch.

| | | | The divider tap and the amplifier input carry one name,
| | | | so they are one node. VOUT = 16×VREF , which is what
| | | | the firmware already assumes.
High-side | driver | returns

## open

## Each IRS2104’s VS pin sat on a net of its own rather than on the switch node it references. The bootstrap capacitor cannot refresh, so neither high-side FET

switches.

VS ties to the power switch node itself.

## Current sense saturated at

1.32 A

## 0.05 Ω × 50 = 2.5 V/A reaches the 3.3 V ADC ceiling at 1.32 A against a 3 A rating. Above that the reading sticks, so the current limit, the CC indicator and the adaptive headroom all stop responding while the ana-

logue loop keeps delivering current.

0.01 Ω with an INA181A3 gives 1 V/A: full scale 3.3 A,

## and a fifth of the shunt dissipation. The trip divider becomes 22k/39k, putting the 3.2 A threshold at 3.2 V

— reachable from the 5 V rail, which it was not before.

Pages follow in order: v0.3, v0.4, v0.5, v0.6 (one sheet each), then v1.1, v1.2, v1.3 (three sheets each — title, power path, control and UI).

# 3 2 Q5 TIP120R4

# LM358 R8

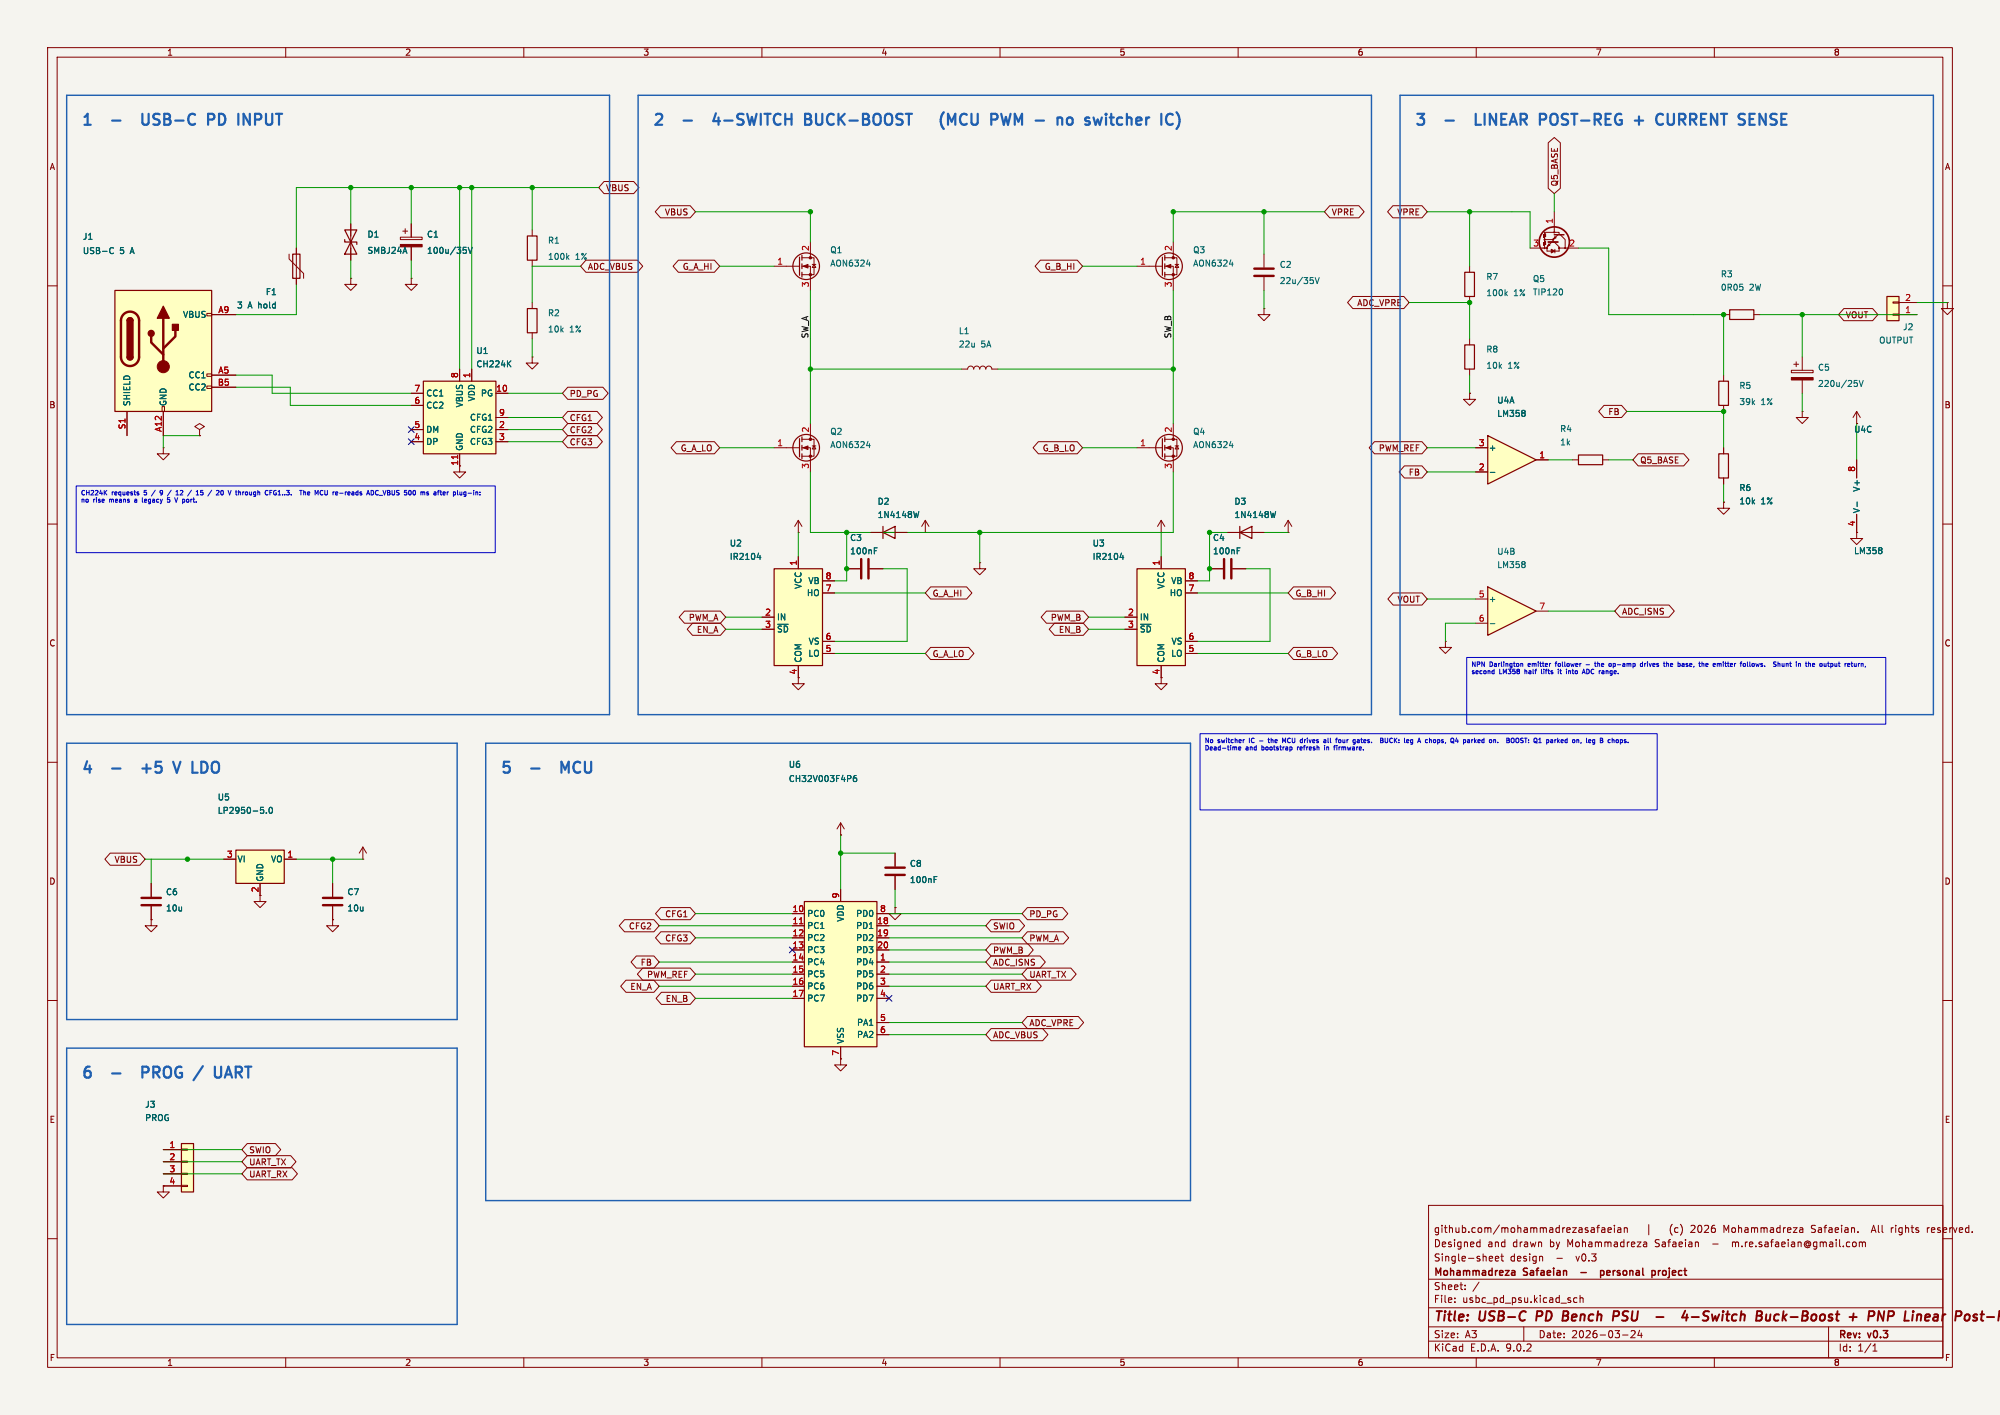
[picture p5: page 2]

# 3 2 Q5 TIP127R4

# LM358 R8

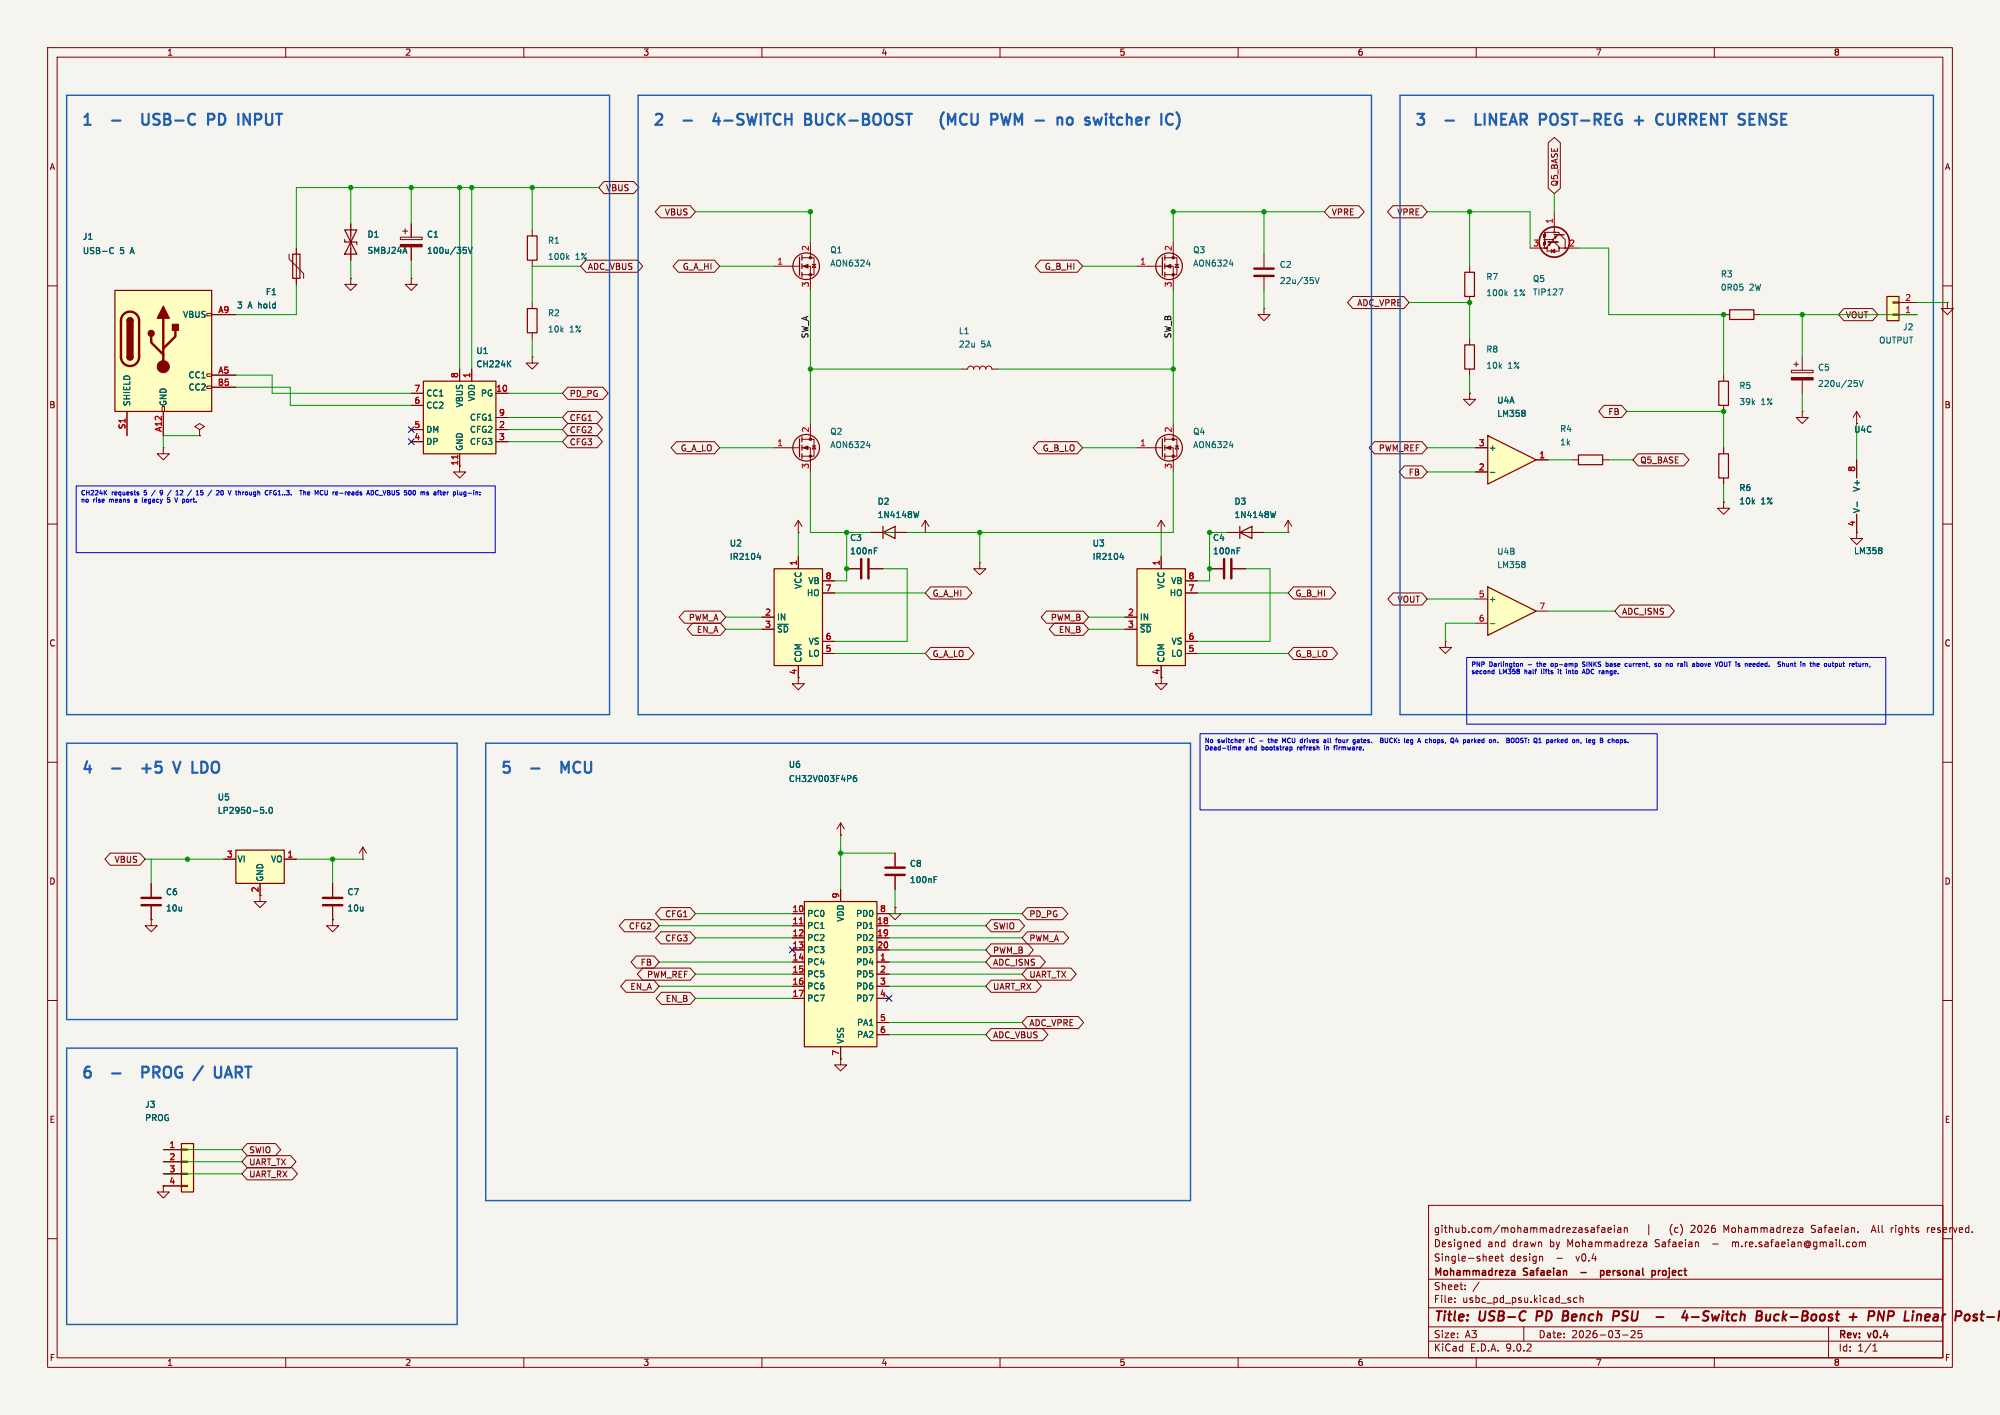
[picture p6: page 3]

D1SMBJ24A | CC1 7 CC2 6 DM 5 DP 4 | VBUS

# LM358 R8

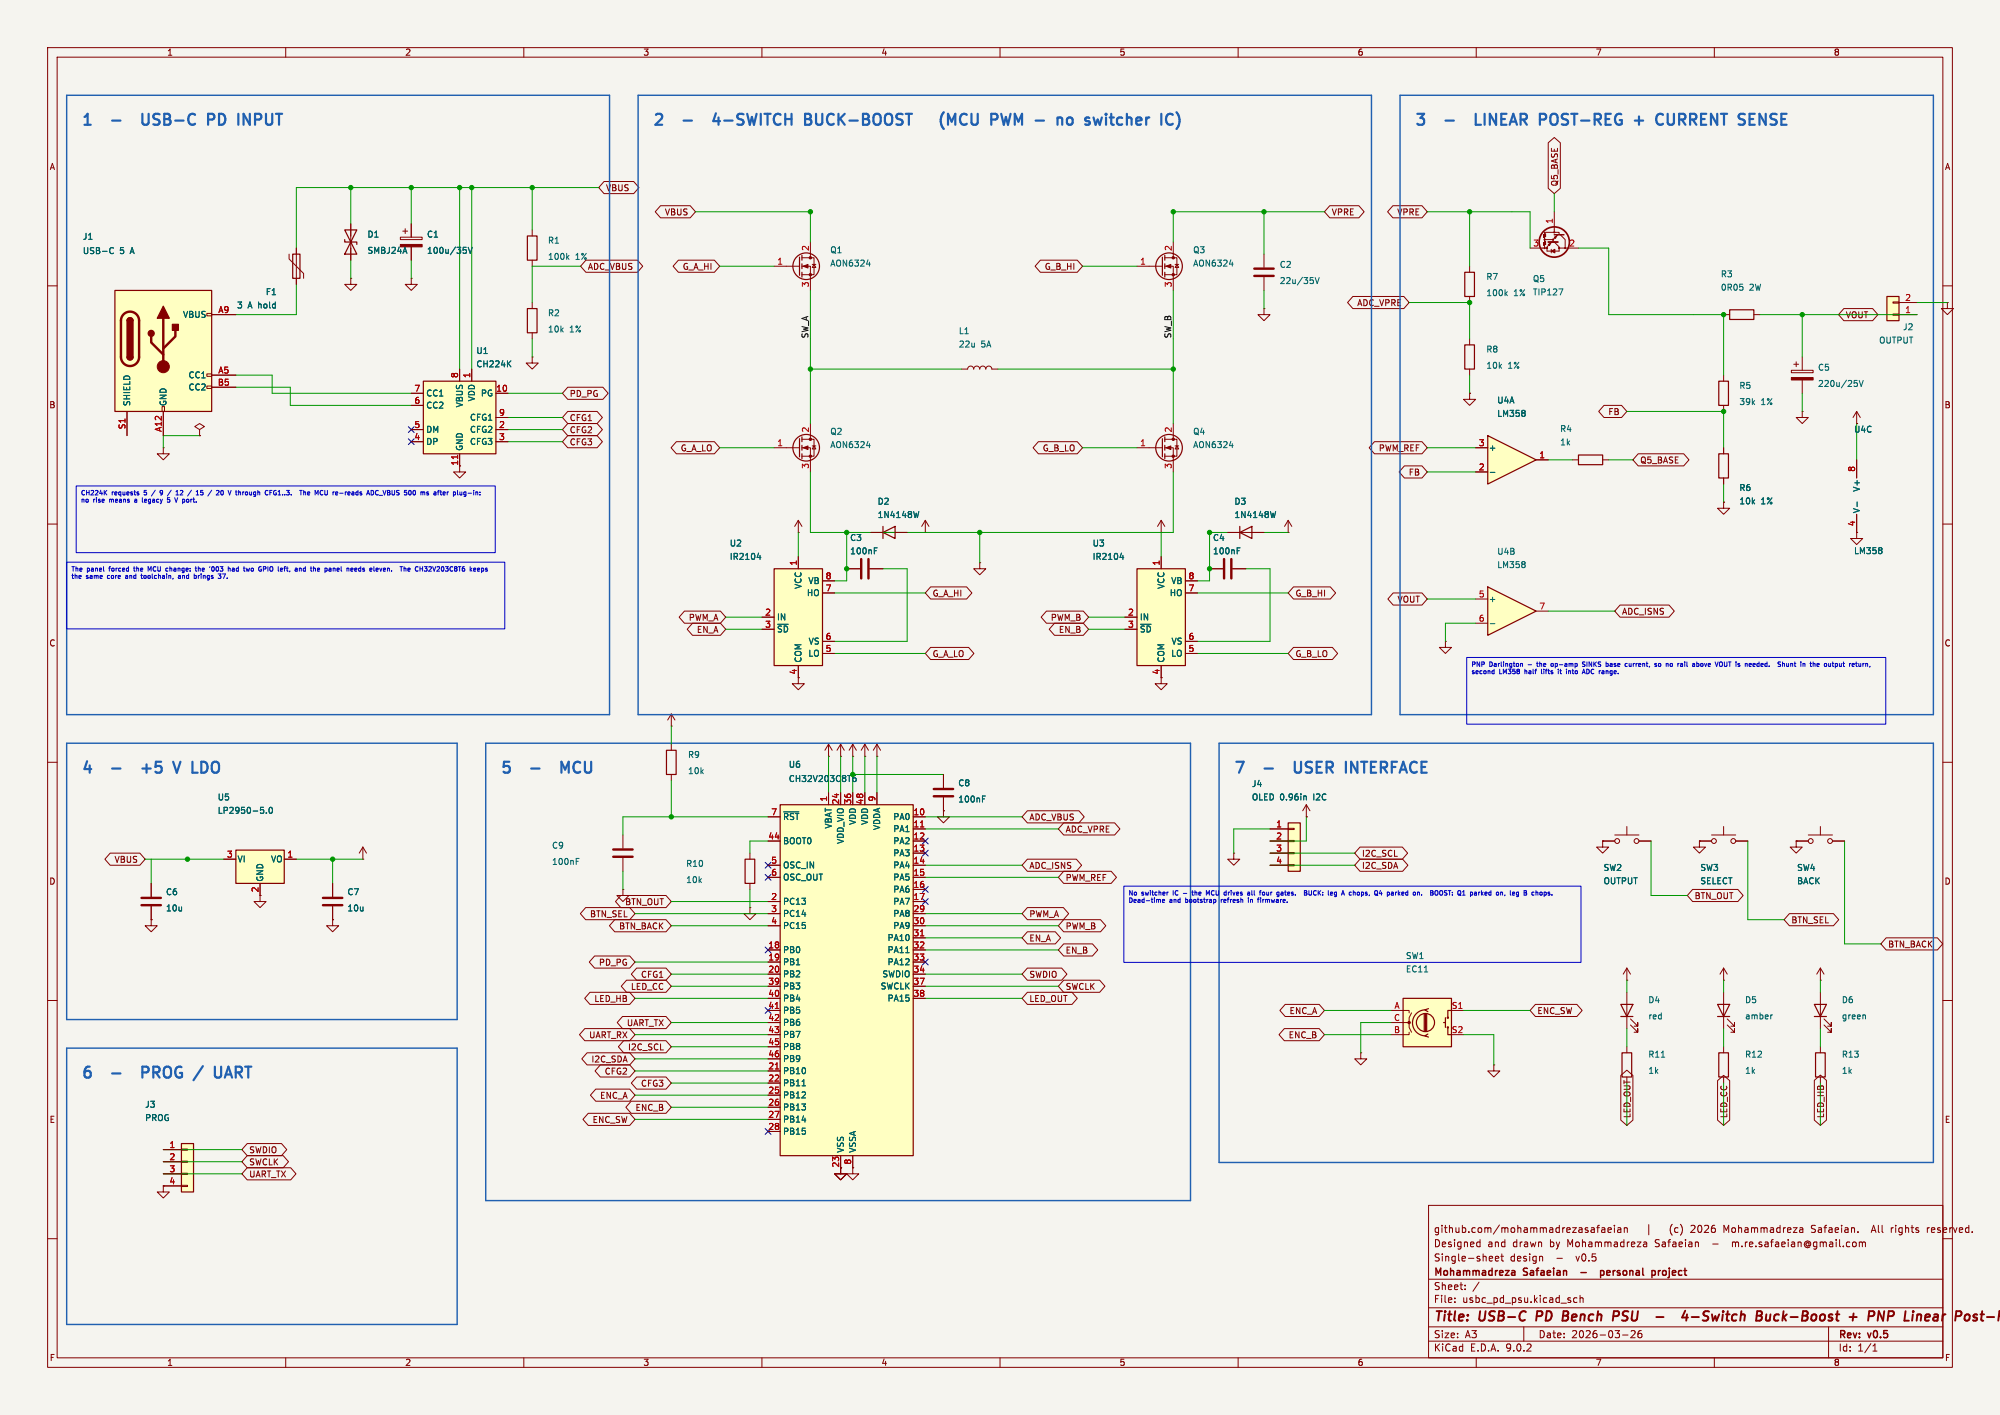
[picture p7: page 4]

9 ~{RST} 7 OSC_IN 5 OSC_OUT 6 PC13 2 PC14 3 PC15 4 PB0 18 PB1 19 PB2 20 PB3 39 PB4 40 PB5 41 PB6 42 PB7 43 PB8 45 PB9 46 PB10 21 PB11 22 PB12 25 PB13 26 PB14 27 PB15 28 VDD 36 VDD 48 PA0 10 PA1 11 PA2 12 PA3 13 PA4 14 PA5 15 PA6 16 PA7 17 PA8 29 PA9 30 PA10 31 PA11 32 PA12 33 SWDIO 34 SWCLK 37 PA15 38 U6 CH32V203C8T6 VI 3 GND

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

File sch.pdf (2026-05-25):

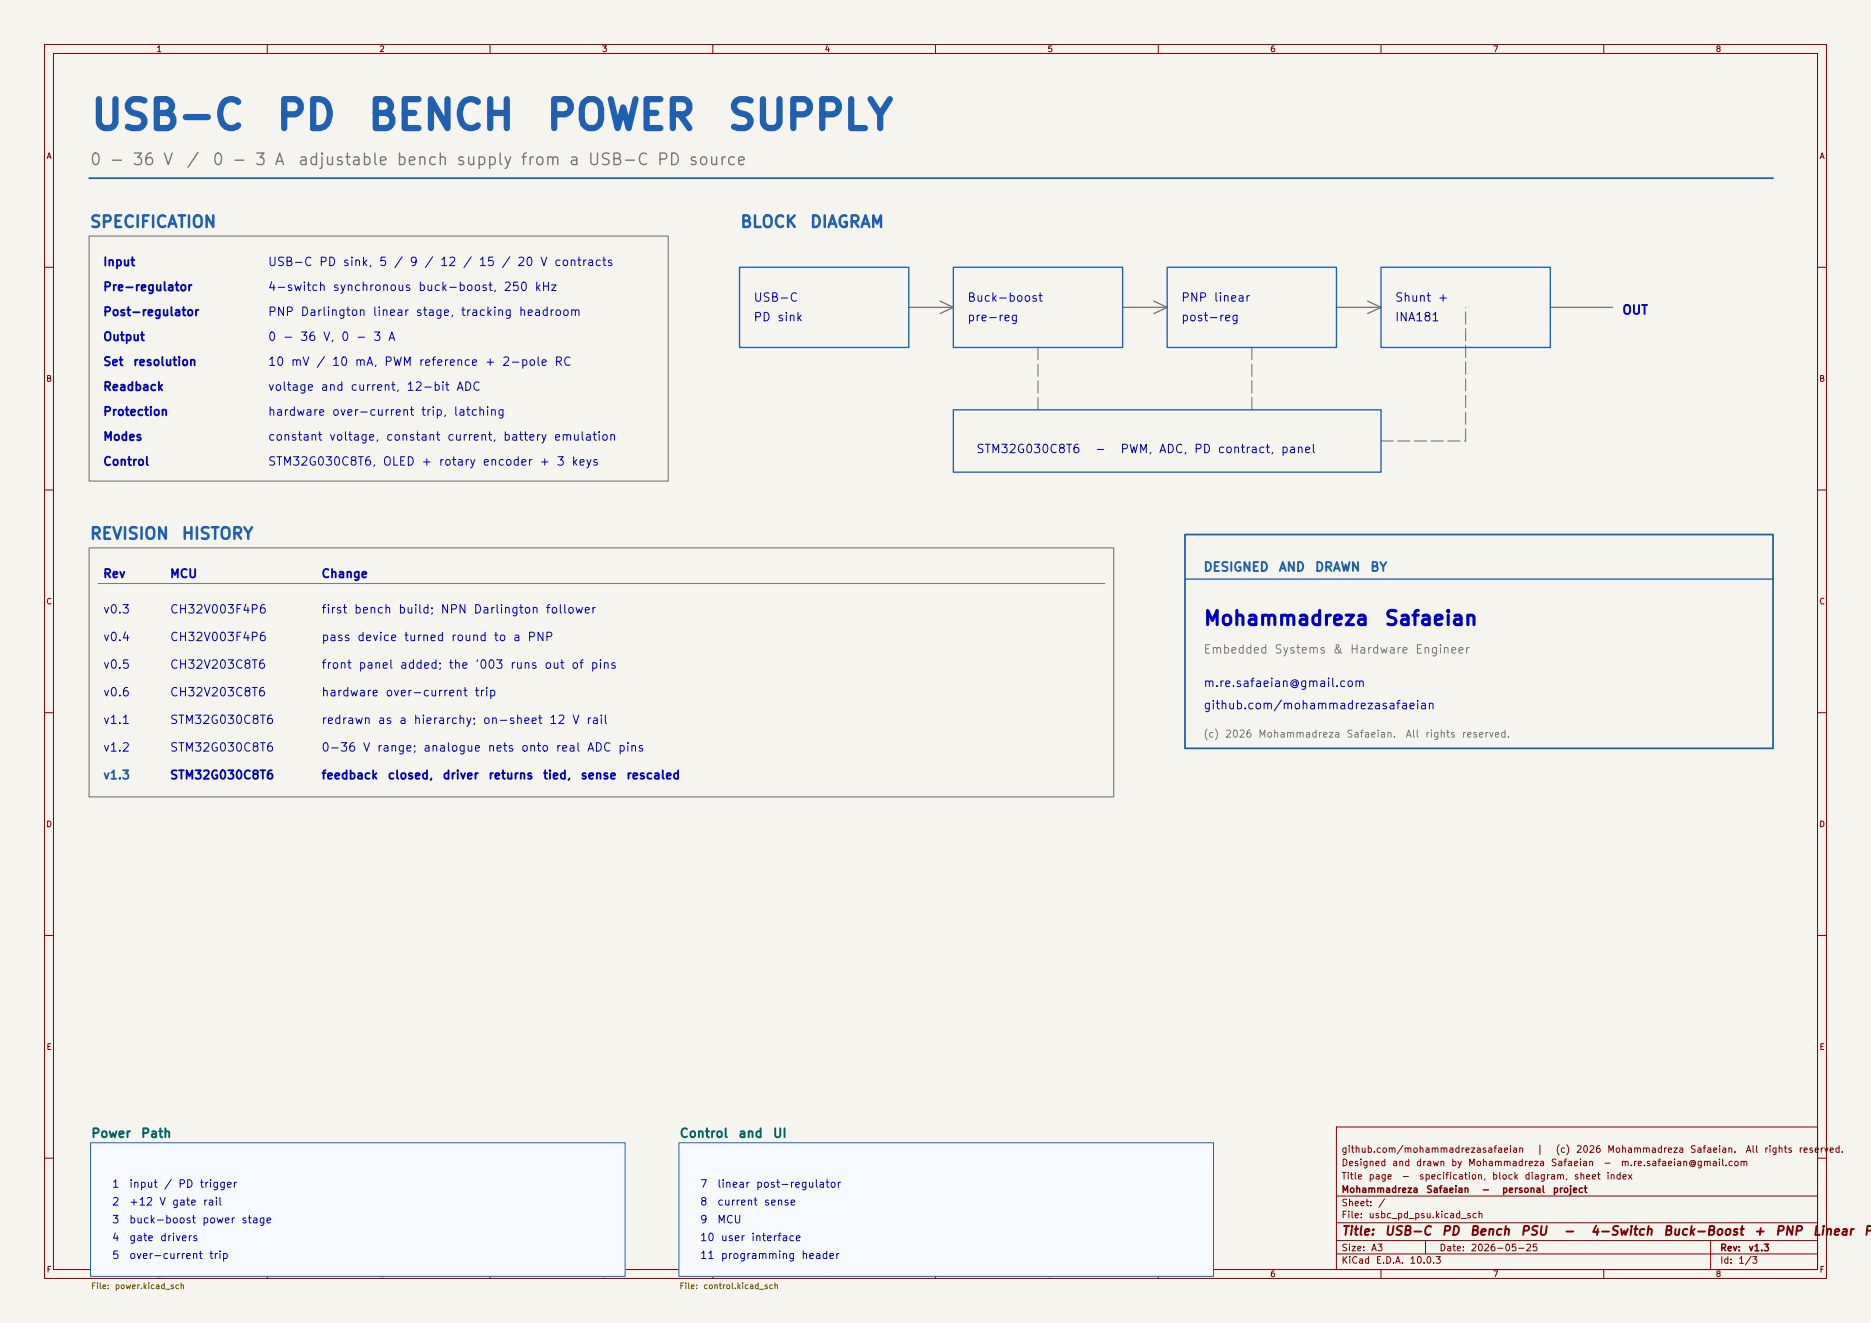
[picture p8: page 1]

USB-C PD BENCH POWER SUPPLY

0 - 36 V / 0 - 3 A adjustable bench supply from a USB-C PD source

USB-C PD sink, 5 / 9 / 12 / 15 / 20 V contracts

4-switch synchronous buck-boost, 250 kHz

PNP Darlington linear stage, tracking headroom

10 mV / 10 mA, PWM reference + 2-pole RC

voltage and current, 12-bit ADC

hardware over-current trip, latching

constant voltage, constant current, battery emulation

STM32G030C8T6 - PWM, ADC, PD contract, panel

STM32G030C8T6, OLED + rotary encoder + 3 keys

DESIGNED AND DRAWN BY

first bench build; NPN Darlington follower

pass device turned round to a PNP

Embedded Systems & Hardware Engineer

front panel added; the '003 runs out of pins

m.re.safaeian@gmail.com
github.com/mohammadrezasafaeian

hardware over-current trip

redrawn as a hierarchy; on-sheet 12 V rail

(c) 2026 Mohammadreza Safaeian. All rights reserved.

0-36 V range; analogue nets onto real ADC pins

feedback closed, driver returns tied, sense rescaled

Control and UI File: control.kicad_sch

github.com/mohammadrezasafaeian | (c) 2026 Mohammadreza Safaeian. All rights reserved.
Designed and drawn by Mohammadreza Safaeian - m.re.safaeian@gmail.com
Title page - specification, block diagram, sheet index
Mohammadreza Safaeian - personal project
Sheet: /
File: usbc_pd_psu.kicad_sch
Title: USB-C PD Bench PSU - 4-Switch Buck-Boost + PNP Linear Post-Regulator

1 input / PD trigger
2 +12 V gate rail
3 buck-boost power stage
4 gate drivers
5 over-current trip

Size: A3 | Rev: v1.3
KiCad E.D.A. 10.0.3 | Id: 1/3 | F Date: 2026-05-25

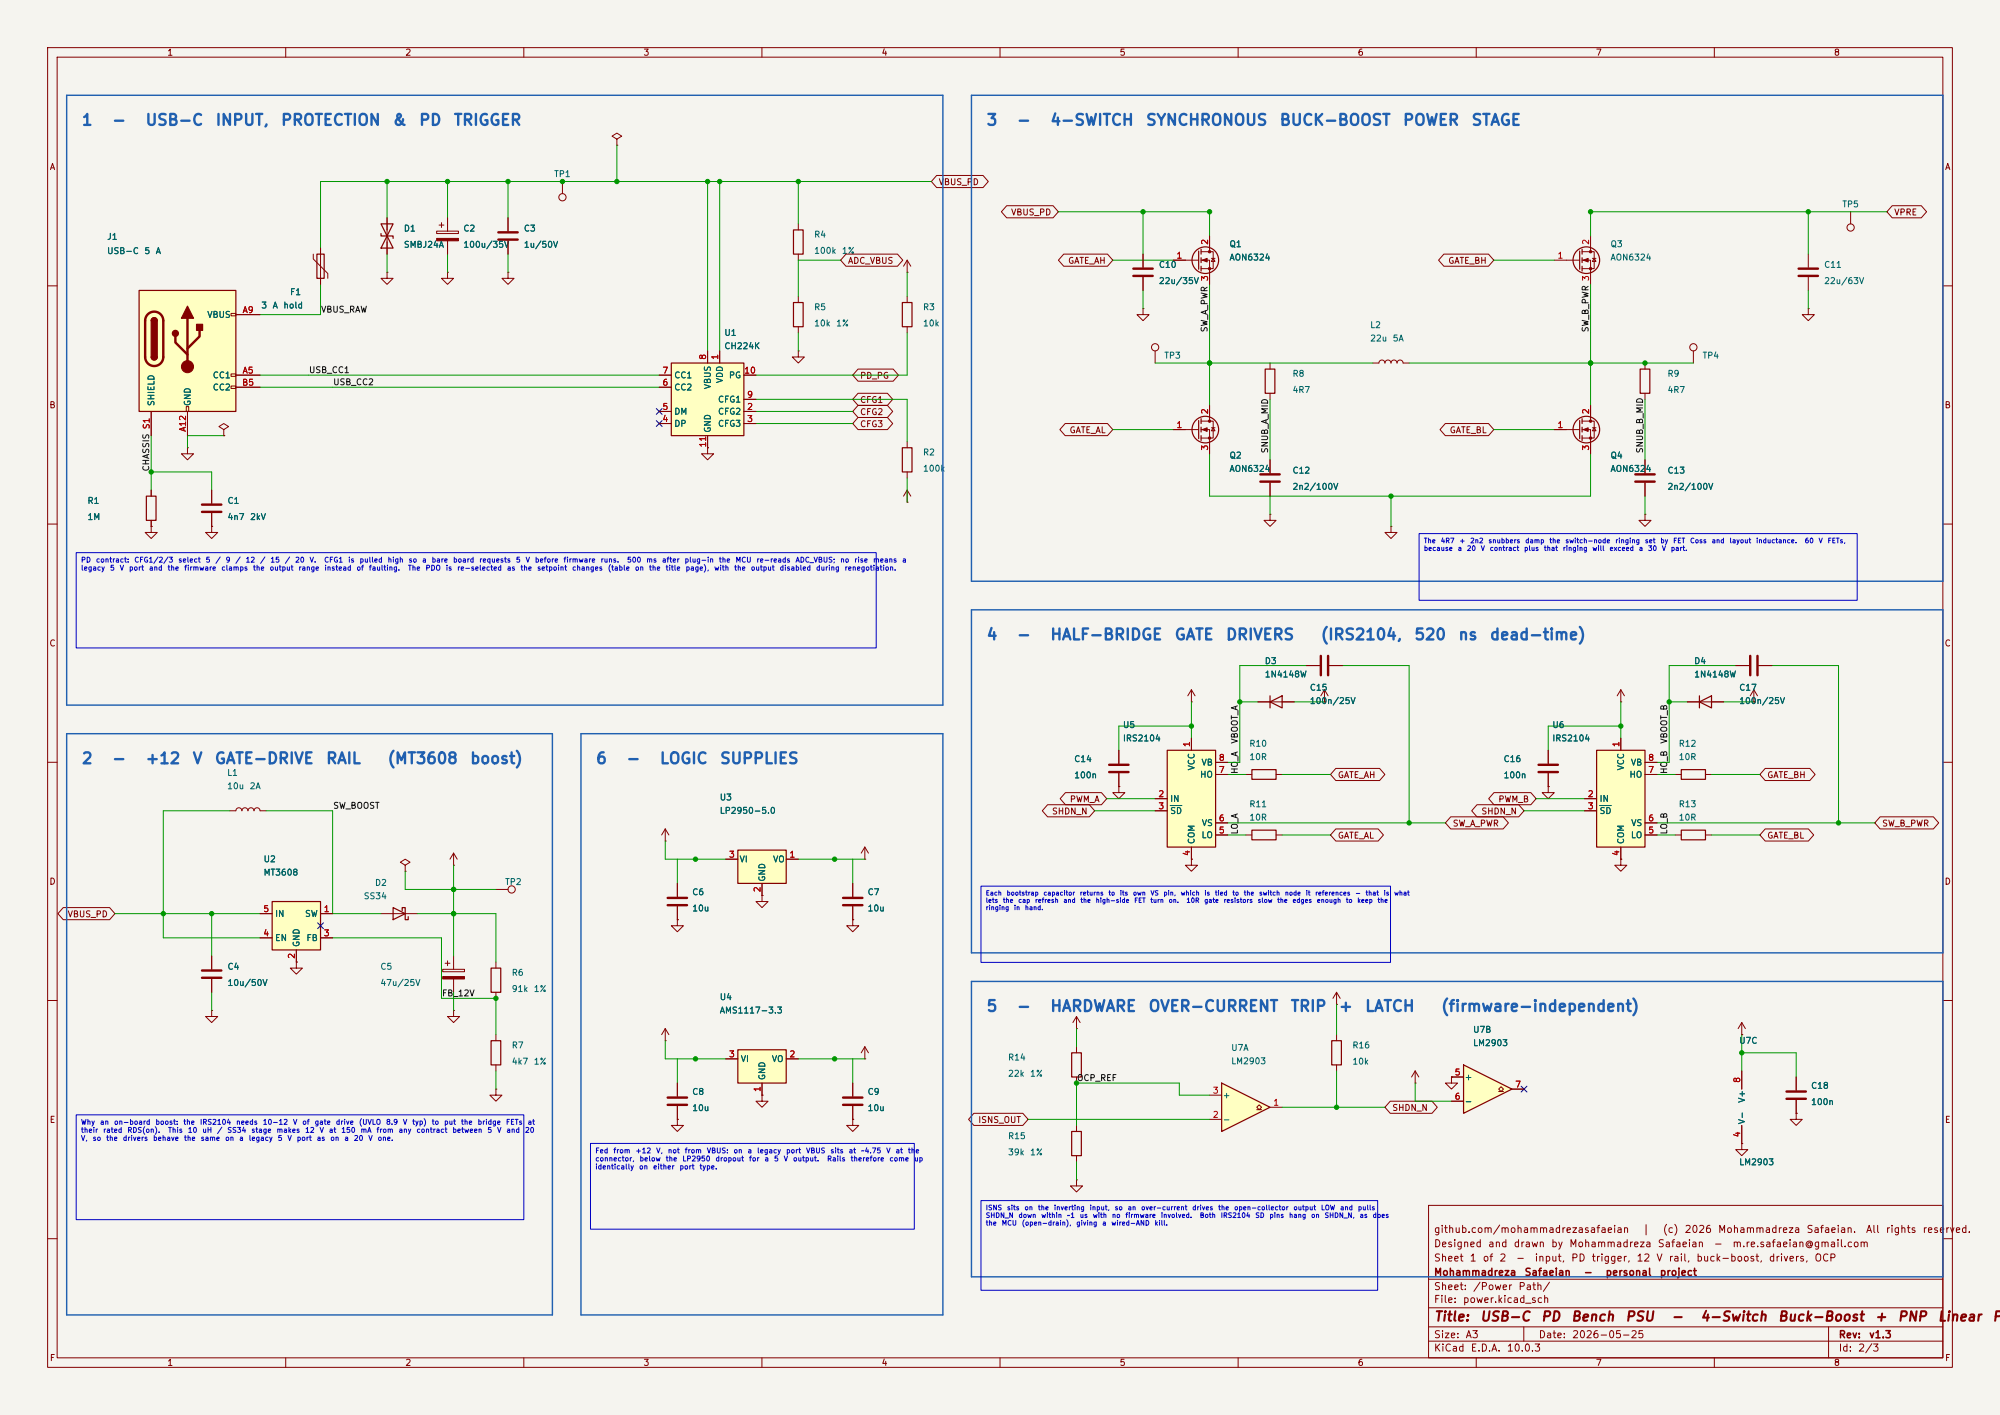
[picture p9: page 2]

PD contract: CFG1/2/3 select 5 / 9 / 12 / 15 / 20 V. CFG1 is pulled high so a bare board requests 5 V before firmware runs. 500 ms after plug-in the MCU re-reads ADC_VBUS; no rise means a
legacy 5 V port and the firmware clamps the output range instead of faulting. The PDO is re-selected as the setpoint changes (table on the title page), with the output disabled during renegotiation.

lets the cap refresh and the high-side FET turn on. 10R gate resistors slow the edges enough to keep the
ringing in hand.

identically on either port type.

ISNS sits on the inverting input, so an over-current drives the open-collector output LOW and pulls SHDN_N down within ~1 us with no firmware involved. Both IRS2104 SD pins hang on SHDN_N, as does

the MCU (open-drain), giving a wired-AND kill.

github.com/mohammadrezasafaeian | (c) 2026 Mohammadreza Safaeian. All rights reserved.
Designed and drawn by Mohammadreza Safaeian - m.re.safaeian@gmail.com
Sheet 1 of 2 - input, PD trigger, 12 V rail, buck-boost, drivers, OCP
Mohammadreza Safaeian - personal project
Sheet: /Power Path/
File: power.kicad_sch

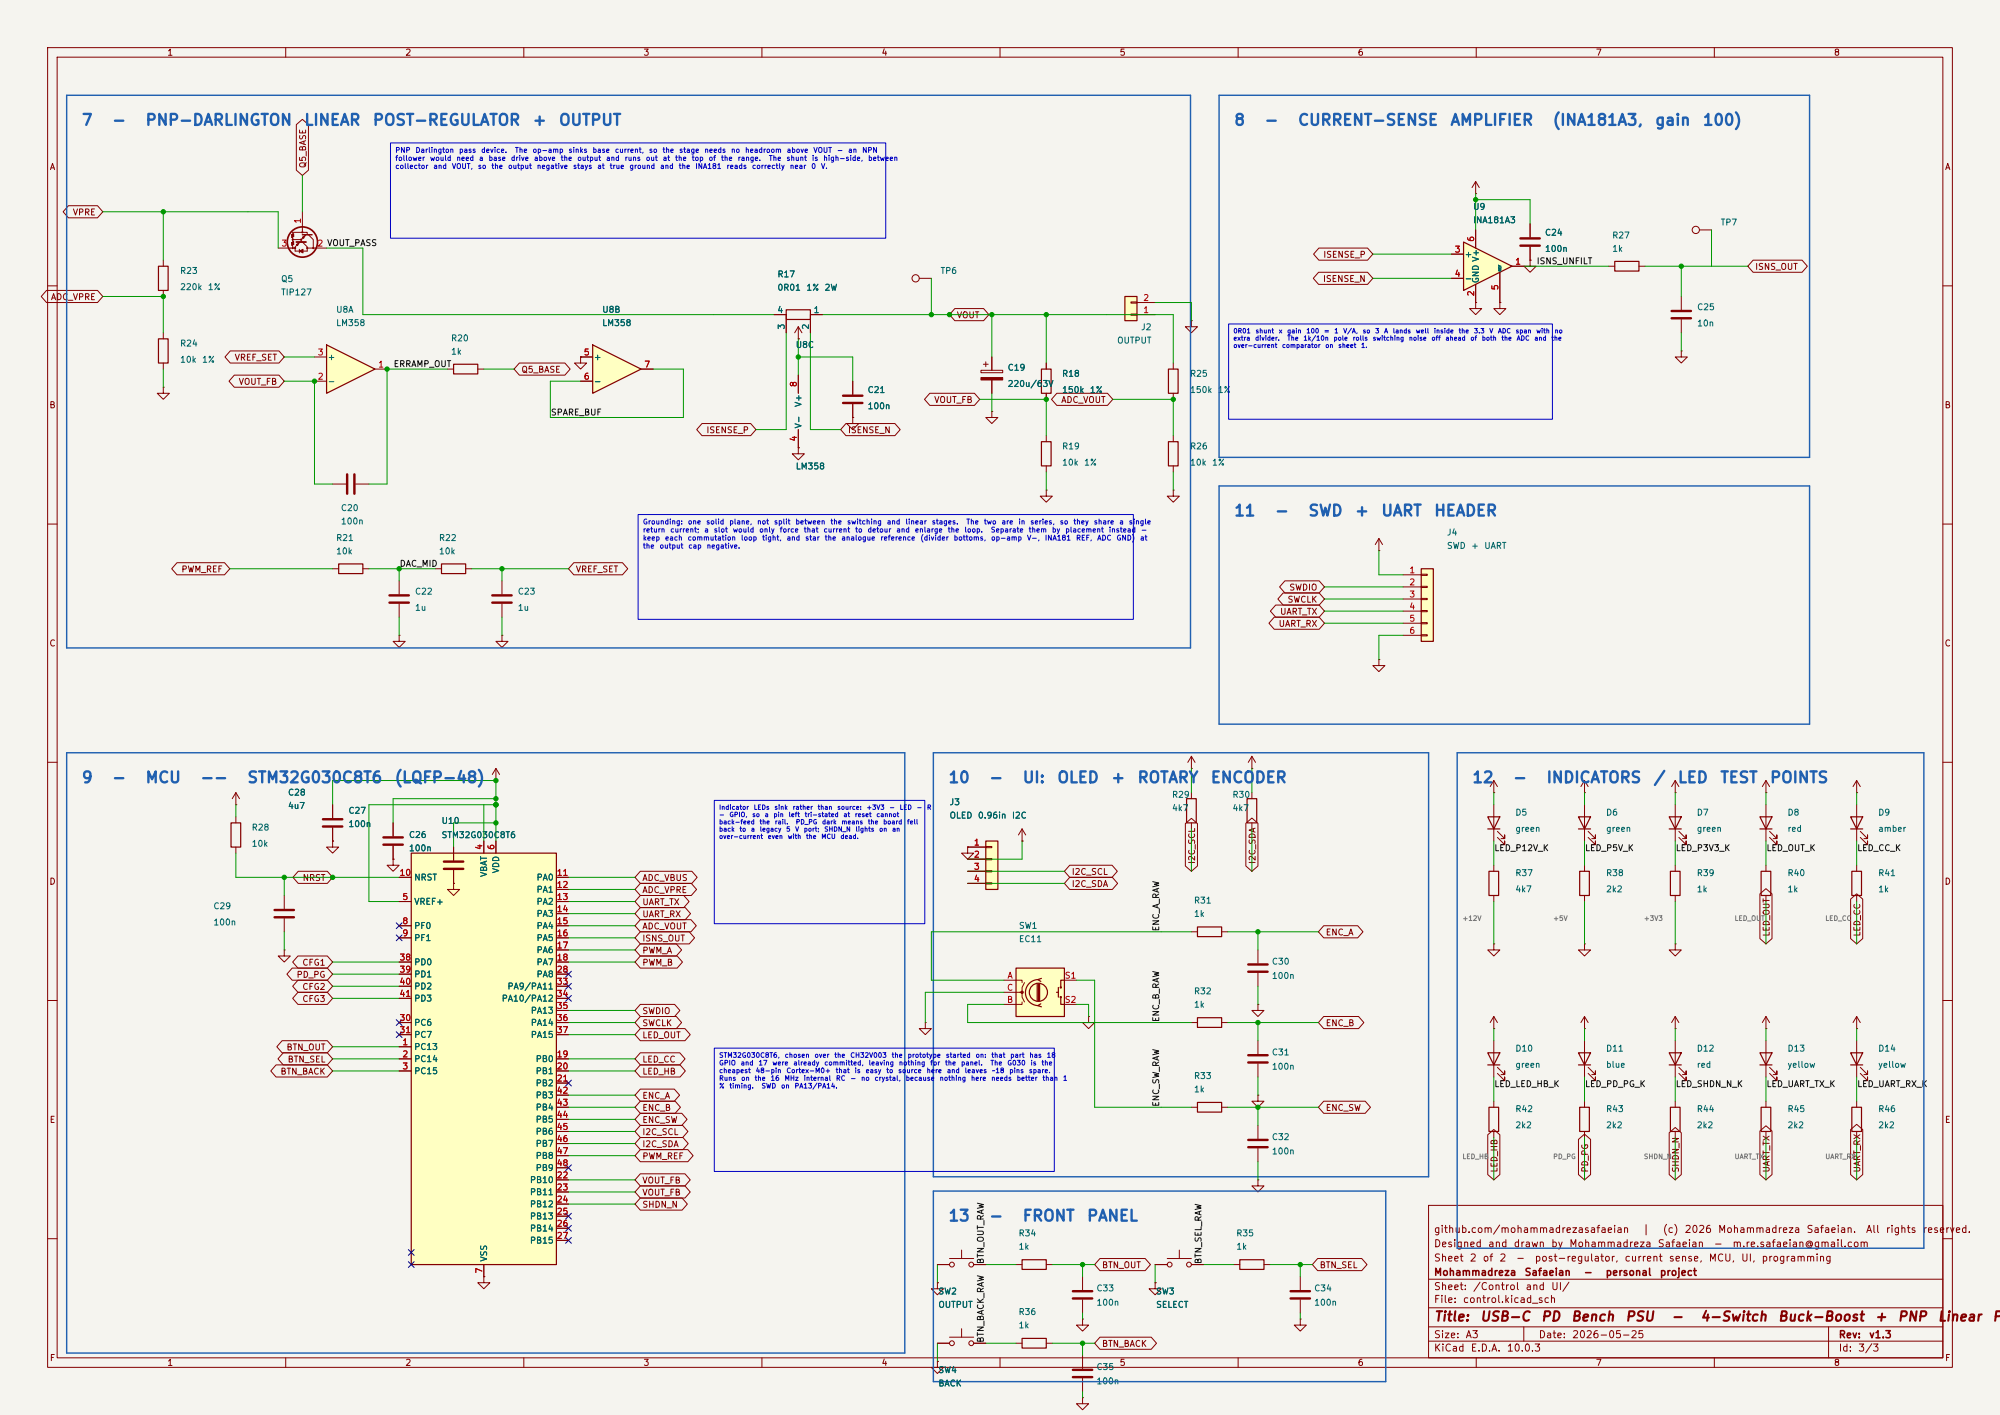
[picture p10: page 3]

7 - PNP-DARLINGTON LINEAR POST-REGULATOR + OUTPUT

8 - CURRENT-SENSE AMPLIFIER (INA181A3, gain 100)

PNP Darlington pass device. The op-amp sinks base current, so the stage needs no headroom above VOUT - an NPN
follower would need a base drive above the output and runs out at the top of the range. The shunt is high-side, between
collector and VOUT, so the output negative stays at true ground and the INA181 reads correctly near 0 V.

return current; a slot would only force that current to detour and enlarge the loop. Separate them by placement instead -
the output cap negative.

Indicator LEDs sink rather than source: +3V3 - LED -over-current even with the MCU dead. | fell back to a legacy 5 V port; SHDN_N lights on an | R - GPIO, so a pin left tri-stated at reset cannot back-feed the rail. PD_PG dark means the board

Designed and drawn by Mohammadreza Safaeian - m.re.safaeian@gmail.com
Sheet 2 of 2 - post-regulator, current sense, MCU, UI, programming
Mohammadreza Safaeian - personal project
Sheet: /Control and UI/
File: control.kicad_sch

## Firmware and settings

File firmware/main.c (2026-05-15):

/* USB-C PD Bench Power Supply - v1.2
 * STM32G030C8T6, bare metal, no HAL.
 *
 *   hw.c       GPIO / ADC / PWM
 *   control.c  PI loop, current limit, battery emulation
 *   pd.c       PDO selection
 *   ui.c       encoder, buttons, LEDs
 *
 * SUPPLY is constant voltage with a current limit; BATTERY emulates a cell
 * as V_out = V_oc - I_load * R_internal. */

#include "psu.h"

struct psu psu = {
    .mode      = MODE_SUPPLY,
    .v_set     = 5000,
    .i_limit   = 1000,
    .bat_v_oc  = 3700,       /* one Li-ion cell */
    .bat_r_int = 100,        /* 100 mOhm        */
};

static void clock_init(void)
{
    /* Reset default HSI16 = 16 MHz, ample for a 5 kHz loop, so no PLL. */
    RCC_IOPENR  |= 0xF;                     /* GPIOA..GPIOD */
    RCC_APBENR1 |= (1u << 1);               /* TIM3         */
    RCC_APBENR2 |= (1u << 20) | (1u << 17); /* ADC, TIM16   */
}

static void gpio_init(void)
{
    gpio_mode_analog(GPIOA, 0);    /* VBUS   */
    gpio_mode_analog(GPIOA, 1);    /* VPRE   */
    gpio_mode_analog(GPIOA, 4);    /* VOUT   */
    gpio_mode_analog(GPIOA, 5);    /* ISENSE */
    gpio_mode_analog(GPIOB, 10);   /* VOUT_FB monitor */
    gpio_mode_analog(GPIOB, 11);   /* VFB_DRV monitor */

    gpio_mode_af(GPIOA, 6, 1);     /* TIM3_CH1  leg A */
    gpio_mode_af(GPIOA, 7, 1);     /* TIM3_CH2  leg B */
    gpio_mode_af(GPIOB, 8, 2);     /* TIM16_CH1 ref DAC */

    gpio_mode_output(PIN_LED_OUT);
    gpio_mode_output(PIN_LED_CC);
    gpio_mode_output(PIN_LED_HB);
    gpio_mode_output(PIN_CFG1);
    gpio_mode_output(PIN_CFG2);
    gpio_mode_output(PIN_CFG3);

    OTYPER(GPIOB) |= (1u << 12);   /* SHDN_N open drain */
    gpio_mode_output(PIN_SHDN_N);
    pin_low(PIN_SHDN_N);           /* start shut down   */

    gpio_mode_input_pullup(PIN_BTN_OUT);
    gpio_mode_input_pullup(PIN_BTN_SEL);
    gpio_mode_input_pullup(PIN_BTN_BACK);
    gpio_mode_input_pullup(PIN_ENC_A);
    gpio_mode_input_pullup(PIN_ENC_B);
    gpio_mode_input_pullup(PIN_ENC_SW);
    gpio_mode_input_pullup(PIN_PD_PG);
}

int main(void)
{
    clock_init();
    gpio_init();
    adc_init();
    pwm_init();

    output_enable(false);
    pd_negotiate();

    /* 5 kHz control, 100 Hz UI. A timer interrupt would be tidier; the busy
     * loop keeps the flow obvious. */
    for (uint32_t tick = 0; ; tick++) {
        control_step();

        if (tick % (LOOP_HZ / UI_HZ) == 0) {
            ui_poll(tick / (LOOP_HZ / 1000));
            pd_follow_setpoint();
        }
    }
}

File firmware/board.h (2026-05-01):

/* Board wiring and scaling, taken from the schematic netlist.
 * The only file that changes if the hardware changes. */

#ifndef BOARD_H
#define BOARD_H

#include "stm32g030.h"

/* Pins expand to (port, number), so calls read pin_high(PIN_LED_CC). */
#define PIN_LED_OUT   GPIOA, 15
#define PIN_LED_CC    GPIOB, 0
#define PIN_LED_HB    GPIOB, 1
#define PIN_SHDN_N    GPIOB, 12      /* open drain, wired-AND with the comparator */

#define PIN_CFG1      GPIOD, 0
#define PIN_CFG2      GPIOD, 2
#define PIN_CFG3      GPIOD, 3
#define PIN_PD_PG     GPIOD, 1

#define PIN_BTN_OUT   GPIOC, 13
#define PIN_BTN_SEL   GPIOC, 14
#define PIN_BTN_BACK  GPIOC, 15
#define PIN_ENC_A     GPIOB, 3
#define PIN_ENC_B     GPIOB, 4
#define PIN_ENC_SW    GPIOB, 5

/* ADC1 channels: PA0/PA1/PA4/PA5 */
#define ADC_CH_VBUS   0
#define ADC_CH_VPRE   1
#define ADC_CH_VOUT   4
#define ADC_CH_ISNS   5

/* Divider ratios in tenths, so the maths stays integer.
 *   VOUT, VPRE 150k/10k = 16.0:1    VBUS 100k/10k = 11.0:1 */
#define VREF_MV        3300
#define ADC_FULL       4095
#define DIV_VOUT_NUM   160
#define DIV_VPRE_NUM   160
#define DIV_VBUS_NUM   110
#define DIV_DEN        10

#define VOUT_MAX_MV    36000
#define IOUT_MAX_MA    3000
#define HEADROOM_MIN   2000          /* mV V_PRE must stay above V_OUT   */
#define HEADROOM_MAX   3000
#define HEADROOM_RI    350           /* extra headroom, microvolts per mA */

#define LOOP_HZ        5000
#define UI_HZ          100
#define PWM_PERIOD     1024          /* shared by the legs and the ref DAC */

#endif

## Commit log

2026-03-23 Add licence and repository skeleton
    MIT licence and the ignore rules: KiCad backups and autosaves, the fp-info
    cache, and the build output the firmware will produce later.
2026-03-23 Add the KiCad project and library tables
    Project file plus the footprint and symbol library tables.
    Both tables point only at the stock KiCad libraries. Nothing here depends on
    a personal library, so the project opens on any machine with KiCad 9
    installed and nothing else.
2026-03-24 v0.3: first working single-sheet arrangement
    The whole supply on one A3 sheet: USB-C PD input with a CH224K trigger, a
    four-switch buck-boost, a linear post-regulator and a shunt in the output
    return.
    The pass device is a TIP120 NPN Darlington wired as an emitter follower,
    which is the obvious way to build the stage: the op-amp pushes the base up
    and the emitter follows it. It regulates, and on the bench at low output it
    behaves.
    No switching-regulator IC. The MCU generates all four gate signals itself,
    which keeps the part count down but makes dead-time and bootstrap refresh a
    firmware problem rather than a hardware one.
    There is no panel. The CH32V003F4P6 has eighteen usable GPIO and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
    [bom.csv, usbc_pd_psu.kicad_sch]
2026-03-25 v0.4: turn the pass device round to a PNP
    The NPN follower cannot reach the top of the range. Its base has to sit two
    Vbe above the output, and the op-amp driving it runs from the same
    pre-regulator rail as the pass device itself, so once the output climbs the
    amplifier saturates before the base gets high enough. The supply simply
    stops following the setpoint near full scale.
    Turning the device round fixes it: a TIP127 PNP Darlington SINKS base current
    instead of sourcing it, so the stage needs no headroom above VOUT at all and
    the pre-regulator only has to stay a dropout above the output.
    Everything else on the sheet is unchanged - same MCU, same buck-boost, same
    shunt in the output ret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
    [bom.csv, usbc_pd_psu.kicad_sch]
2026-03-26 v0.5: add the front panel, and the MCU it needs
    OLED, rotary encoder with its push, three keys and three indicator lamps.
    Adding the panel needs eleven more pins and only two were left, so the MCU
    moves up to a CH32V203C8T6. Same RISC-V family, same toolchain, same
    programming header - forty-eight pins instead of twenty, of which thirty-seven
    are usable. Nothing else on the sheet changes.
    Choosing within the family rather than switching vendor keeps the existing
    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
    [bom.csv, usbc_pd_psu.kicad_sch]
2026-03-27 v0.6: hardware over-current trip
    A comparator watches the sense amplifier and pulls the driver enable low
    directly.
    Bench testing with a deliberate short showed the firmware loop cannot react in
    time: by the time a 5 kHz loop notices, the FETs have already taken the
    current. The trip has to be hardware, and it has to bypass the MCU entirely.
    This is also where the single-sheet layout runs out of room. Everything still
    fits, but only just, and the next thing added will not.
    [bom.csv, usbc_pd_psu.kicad_sch]
2026-04-05 Split the design into a hierarchy
    Three sheets: a title page carrying the specification and the sheet index, the
    power path, and the control and user interface.
    The single sheet had become unreadable and there was no space left for the
    gate-drive rail the design still needs. Splitting it also means the power
    stage and the control side can be worked on without one disturbing the other.
    Nets that cross a sheet boundary use global labels, which is the only
    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
    [bom.csv, control.kicad_sch, power.kicad_sch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]
2026-04-15 v1.1: multi-sheet redraw on an STM32G030
    The redraw, and with it a change of MCU.
    The CH32V203 would have done the job, but the STM32G030C8T6 is easier to buy
    here, is the cheapest 48-pin Cortex-M0+ of the group, and brings a toolchain
    that does not depend on a single vendor's programmer. The pin budget is
    similar; the availability is not.
    Three things the prototype could not do are fixed here:
    - the +12 V gate-drive rail becomes a real boost converter on the sheet rather
    than an off-sheet module, so the board can actually be built. The IRS2104
    needs 10-12 V of gate drive and a legacy 5 V port cannot supply it.
    - RC snubbers across both switch nodes, damping the ringing that the FET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
    [bom.csv]
2026-04-18 Add rendered previews of each sheet
    A PNG per page so the schematic can be read on the repository page without
    downloading the PDF or installing KiCad.
2026-04-21 Write the README and the authorship note
    What the supply does, how the two stages divide the work, why the headroom
    tracks the output, and what it costs to build.
    The authorship note records which parts of the design are mine and which are
    stock library symbols and footprints, which is worth stating plainly on a
    portfolio project.
2026-04-23 Check the schematic against the netlist
    Went through the exported netlist looking for the mistakes ERC cannot catch:
    parts with no footprint, two-terminal parts shorted end to end, nets with a
    single node, labels differing by a character, symbols outside a frame.
    Six checks pass. Two do not, and both are recorded in netlist-review.md:
    the four analogue nets are on pins with no ADC channel, and the feedback
    divider never reaches the error amplifier.
    The first is a pin move and is fixed next. The second needs more thought.
2026-04-25 v1.2: 0-36 V range, and analogue nets onto real ADC pins
    Two changes, one of them serious.
    The serious one: ADC_VBUS, ADC_VPRE, ADC_VOUT and ISNS_OUT were on PD2, PD3,
    PC6 and PC7. None of those four pins has an ADC channel on this part, so not
    one of the four measurements could ever have been taken. They move to PA0,
    PA1, PA4 and PA5 - ADC_IN0, 1, 4 and 5 - and the timer outputs shuffle to
    suit.
    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
    [bom.csv, control.kicad_sch, power.kicad_sch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]
2026-04-29 Add the register map and enable the peripheral clocks
    Just the registers this design touches: RCC, GPIO, ADC, TIM3 and TIM16.
    Written out rather than included from a vendor header so every offset in the
    firmware can be traced to a line in the reference manual.
    Clocks are enabled for GPIOA..D, TIM3, TIM16 and the ADC. Everything else
    stays off - a peripheral with no clock cannot surprise you.
2026-05-01 Add the board pin map, shared state and GPIO bring-up
    board.h is the only file that changes if the hardware changes: every pin, every
    divider ratio, every limit. Pins expand to (port, number) so a call reads
    pin_high(PIN_LED_CC) rather than a bit position.
    psu.h holds the shared state - setpoint, limit, measurements, fault - and the
    handful of calls that cross a module boundary.
    GPIO bring-up puts SHDN_N in open-drain and drives it low, so the output is
    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
2026-05-03 Read the four analogue channels and scale them to mV and mA
    Calibrate, enable, then read each channel four times and average.
    Four samples because the switching noise sits far above the loop bandwidth: a
    short average removes it without slowing the loop down. The sampling time is
    long, since the dividers are high-impedance and the sample-and-hold needs time
    to settle.
    Scaling is integer throughout - counts to millivolts at the pin, then the
    divider ratio in tenths to millivolts at the node. No floating point anywhere
    in the measurement path.
    [hw.c, main.c]
2026-05-05 Add the leg PWM, the reference DAC and the output enable path
    TIM3 drives the two buck-boost legs, TIM16 produces the reference the analogue
    loop follows through its RC filter.
    The reference is a PWM duty rather than a DAC because the G030 has no DAC. The
    analogue chain scales it by the same 16:1 as the feedback divider, so duty maps
    straight onto the setpoint with no conversion.
    output_enable() can only ever pull SHDN_N low; releasing it hands the node back
    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
2026-05-07 Add the pre-regulator PI loop with adaptive headroom
    The analogue loop holds the output; this only keeps the pre-regulator a little
    way above it.
    Headroom is 1.6 V plus 0.35 V per amp, clamped between 2 and 3 V. A flat 2 V
    is too thin at 3 A once the Darlington saturation voltage, the shunt drop and
    the switcher's own droop are added up; more than 3 V is just heat in the pass
    device.
    One leg chops and the other parks, chosen by comparing the wanted pre-regulator
    voltage against the bus. That is what makes it a four-switch buck-boost rather
    than two converters in series, and it means switching loss is paid once.
    [main.c]
2026-05-09 Add the firmware current limit and the two protection trips
    Current limit walks the reference down when the measured current passes the
    setting, which is a regulation mode rather than a fault - the supply drops into
    constant current and stays there.
    Two trips latch instead: output above the maximum by more than 2 V, and the
    pre-regulator falling below the output, which means tracking has been lost and
    the pass device is about to be reverse-biased.
    The hard over-current trip is the comparator on the board. This is the soft
    one.
2026-05-11 Add battery emulation as a second operating mode
    A cell sags under load, and that is the whole model:
    V_out = V_oc - I_load * R_internal
    Open-circuit voltage and internal resistance are both adjustable from the
    panel - 3.7 V and 100 mOhm for a lithium cell, 12.6 V and 20 mOhm for a small
    lead-acid pack.
    The sense and the reference already exist for normal regulation, so the mode
    costs six lines and no extra hardware.
2026-05-13 Select the PD contract from the setpoint and follow it at runtime
    The buck-boost decouples input from output, so any contract can reach any
    output voltage. The choice is about keeping the duty cycle controllable and
    the conversion ratio small, not about reachability.
    Boundaries carry hysteresis so a setpoint sitting near one does not renegotiate
    repeatedly, and the output is disabled across a renegotiation because VBUS
    collapses briefly while the source changes voltage.
    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
2026-05-17 Fix the PWM period being written to PSC instead of ARR
    pwm_init() wrote the period to the prescaler.
    The two registers are adjacent - 0x28 and 0x2C - and the wrong one compiled
    perfectly happily. The effect was that the prescaler became 1023 while the
    auto-reload stayed at its reset value of 0xFFFF, so the carrier came out at
    16 MHz / 1024 / 65536, about a quarter of a hertz instead of 15.6 kHz, and the
    reference DAC's full scale collapsed to 1023/65535 - about 1.6 % duty.
    Nothing would have regulated. Worth recording rather than quietly correcting,
    because the failure mode is silent: the code runs, the timer runs, and every
    number it produces is wrong.
    [hw.c]
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2026-05-25 v1.3: close the feedback loop, tie the driver returns, rescale the sense chain
    Three faults, each of which on its own would have stopped the board working.
    All three came out of reading the exported netlist rather than the schematic.
    The feedback loop was never closed. The output divider tap and the error
    amplifier's inverting input were two separate nets: the divider went only to an
    MCU analogue input, and the amplifier input saw only its compensation
    capacitor. With no DC path around it the amplifier is a bare integrator - its
    input floats on bias current and its output ramps to a rail - so the pass
    device would have sat hard on or hard off. The output would not have
    regulated; it woul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
    [bom.csv, control.kicad_sch, power.kicad_sch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]
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

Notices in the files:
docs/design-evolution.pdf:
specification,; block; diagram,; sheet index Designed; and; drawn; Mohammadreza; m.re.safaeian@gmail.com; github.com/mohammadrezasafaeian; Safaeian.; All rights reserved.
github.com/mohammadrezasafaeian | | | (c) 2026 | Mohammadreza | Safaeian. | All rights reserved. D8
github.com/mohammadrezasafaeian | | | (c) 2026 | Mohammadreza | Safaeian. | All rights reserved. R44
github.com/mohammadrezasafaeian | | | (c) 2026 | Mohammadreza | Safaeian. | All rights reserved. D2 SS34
